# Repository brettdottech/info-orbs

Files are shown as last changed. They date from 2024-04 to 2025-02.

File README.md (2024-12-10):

# Welcome to Info Orbs
Info Orbs is an open source display widget built on top of the ESP32 platform. The device can be used to display a variety of different widgets catered to many different use cases (:

**Version 1.1 of the firmware is here, you can find the new features outlined below. If you're coming from Youtube, the software flashing instructions have changed slightly, *please refer to *[the NEW FLASHING INSTRUCTIONS](references/Firmware%20Install%20Guide.md)* to ensure you get up and running smoothly.***

Quick Links: [Get A Dev Kit Here](https://brett.tech/collections/electronics-projects/products/info-orbs-full-dev-kit) | [Discord](https://link.brett.tech/discord) | [Youtube Assembly/Flashing Video](https://link.brett.tech/orbsYT)
<p>
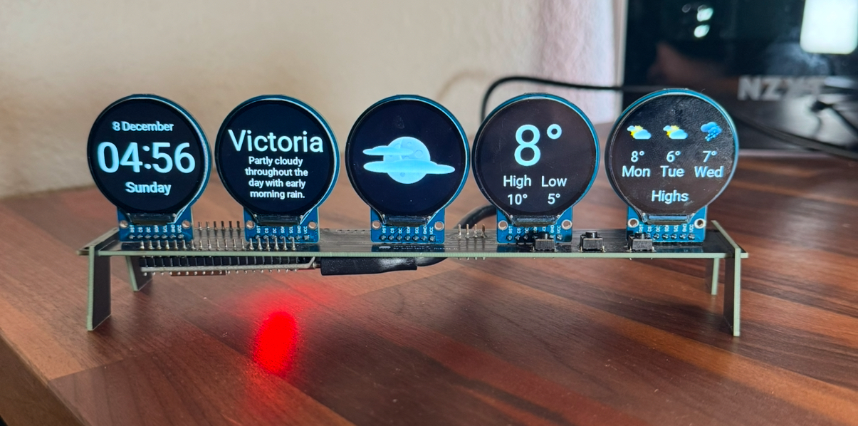
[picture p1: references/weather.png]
Weather Widget
    
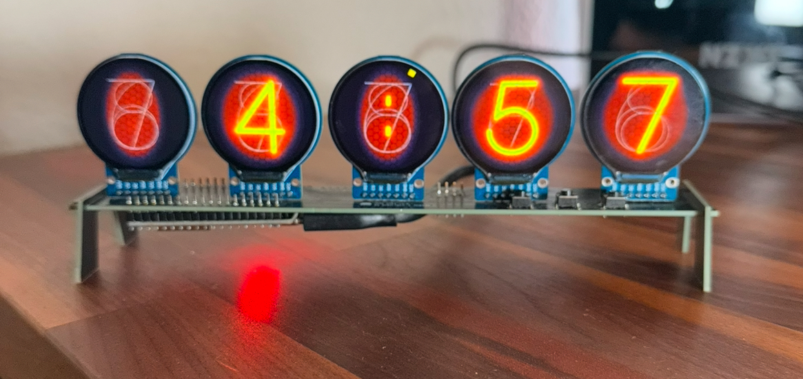
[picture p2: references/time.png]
Clock Widget
    
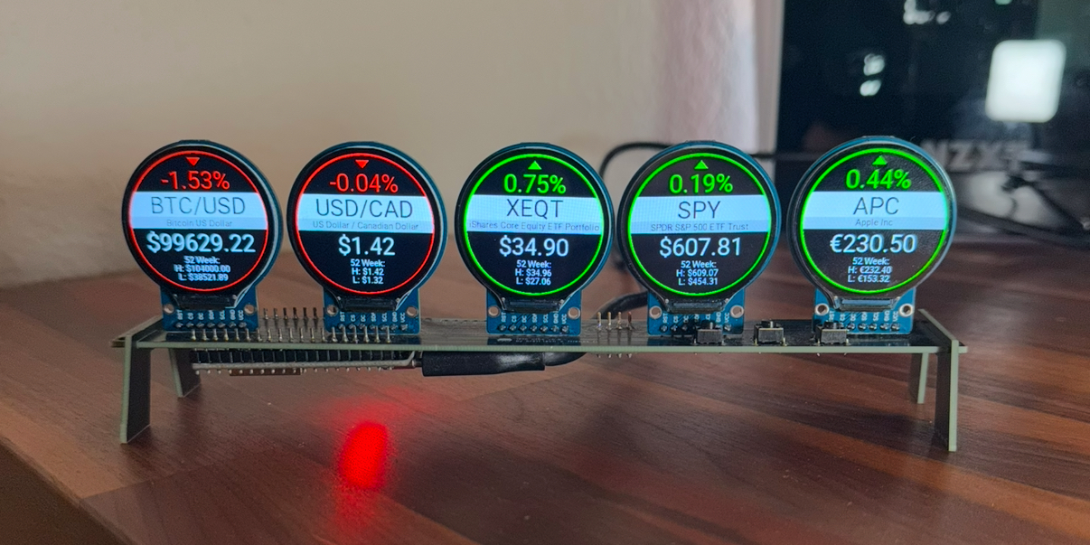
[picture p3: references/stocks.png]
Stock Widget
    
</p>

## First, a few housekeeping items for anyone interested in helping with this project, or building one for themselves

- If you want to contribute and or need a hand with setup, please pop over to the [Discord](https://link.brett.tech/discord). Make sure to select you're there for info orbs when filling out the onboarding questionnaire in order to get placed in the right channels

- I've put together dev kits consisting of all the parts you need to build this project [you can buy them here.](https://brett.tech/collections/electronics-projects/products/info-orbs-full-dev-kit)  They're $60 and will save you a bunch of time and hassle, and are a great way to support the project (:

- I've put together a brief [Youtube Video](https://link.brett.tech/orbsYT) walking through the soldering and flashing for anyone that needs a hand assembling.
## Version 1.1 Release

Version 1.1 is here, in the future releases will be more frequent, but this one is a BIG one bringing some incredible functionality to the project.

**1.1 Changes:**

 1. WifiManager added allowing users to configure/change their Wifi credentials using a friendly in-browser portal.
 2. TTF fonts, giving us much more flexibility in the fonts we use and how they're scaled.
 3. Updated Stock widget with a new look and now supporting international markets, different currencies, crypto and forex.
 4. Nixie Tube clock
 5. Support for users to create their own clocks by simply uploading images for digit
 6. Weather widget "dark mode"
 7. Widget auto-scrolling (switch between widgets automatically ever x seconds)
 8. Screen "Dimming" during certain hours of the day. This is artificial dimming through way of adjusting the colours to be less saturated, but it works very well.
 9. Medium & long press button support to allow for further on device configurations
 10. MQTT widget introduced to display data from and MQTT broker, with a [home assistant blueprint available](https://github.com/dreed47/info-orbs-mqtt-ha).  
 11. Multi Language support for the weather widget

 ..plus LOTS more, this was a big one, thank you to all of the community members who made this update happen. I'm excited we get to finally roll it out and share it with you.
## Getting Up And Running

### 1. Hardware/Wiring
If you use the PCB soldering should be straight forward, however if you want to wire thing up yourself the pinouts are below:

    DSP-----ESP
    SDA -> G17 
    SCLK -> G23 
    DC -> G19 
    RST -> G18
    VCC - >5V/VCC 
    GND -> GND
    Screen1 CS -> G13
    Screen2 CS -> G33
    Screen3 CS -> G32 
    Screen4 CS -> G25
    Screen5 CS -> G21

   Lastly, three pushbuttons between `VCC/5V` and `G14,G26,G27.`
Diagram can be seen below:
Wiring Diagram

### 2. Dev Environment Setup Config
**IDE Setup**
Start by downloading the most recent codebase from the `main` branch. Should you want to explore the latest and greatest features, you can try flashing the `dev` branch by changing the dropdown at the top left, however this version will be poorly documented and less stable.
While built on Arduino, the codebase for this project has been built using the  [Platform IO IDE](https://platformio.org/), which allows you to compile/run Arduino code in VSC as well as quite a few other creature comfort items.
Once you have platform.io installed and configured in VSC, open the `info-orbs.code-workspace` to being the setup process.

**Project Configuration**
Before compiling/flashing, you'll need to navigate into `firmware` >>`config` directory and make a copy of the file `config.h.template` in the same folder and rename that copy to `config.h` **THIS STEP IS CRITICAL AND YOUR CODE WILL NOT COMPILE IF YOU DONT COPY THIS FILE AND CHANGE THE NAME**

Lastly, open up the `config.h` file you just copied/renamed and adjust the parameters in this file to configure the orbs to your personal needs. You can find more details about each configuration option below.

Once you're done this, you can flash the firmware to your orbs by holding the "boot" button on the ESP32 and clicking the "Upload" arrow at the very bottom bar of VSC.

### 3. Widget Options & Configuration
**Basic Setup Fields**
- Wifi is now configured on device using WifiManager by connected to the devices access point upon boot. However if this does not work, you may manually configure your wifi details using the fields in the config file (only do this as a last resort.)  
  ```c
  //#define WIFI_SSID "MyWiFiRouter" // Wifi router SSID name (use only 2.4 GHz   network)    
  //#define WIFI_PASS "WiFiPassword" // Wifi router password  
  ```
- Timezone configuration, you will need to change the below field to your local timezone, or timezone you want displayed on the devices clock(s). Please copy/paste the exact timezone as outline in this list <https://timezonedb.com/time-zones>  
  ```c
  #define TIMEZONE_API_LOCATION "America/Vancouver" // Use timezone from this   list: https://timezonedb.com/time-zones
  ```

- If you want your orbs to automatically cycle widgets, you can change the number from 0 in the below line of code for how many seconds you want to wait between switching, and this will enable that functionality
  ```c
  #define WIDGET_CYCLE_DELAY 0 // Automatically cycle widgets every X seconds, set   to 0 to disable
  ```

- If you want your orbs to "dim" at certain hours of the day you need to uncomment (remove the `//`  at the beginning of the below three lines of code then adjust the starting hour, ending hour, and brightness which you want the dimming to occur.
  ```c
  //#define DIM_START_HOUR 22  // Dim the screens at this time (24h format)
  //#define DIM_END_HOUR 7     // Undim the screens at this time (24h format)
  //#define DIM_BRIGHTNESS 128 // Dim brightness (0-255)
  ```

**Widgets & Widget Settings**
1. **Clock** (Enabled By Default) - this will show the time on the orbs with multiple means of customization. The default settings for the clock will switch between the default and "nixie" style clock upon a short press of the middle button. It will switch between 12/24 hours by a medium press(~0.5 seconds) of the same middle button. The clock has many other configureable elements that can be found in config.h as shown below, feel free to mess around with them to make it your own (:
   ```c
   // CLOCK CONFIGURATION
   # define FORMAT_24_HOUR false            // Toggle 24 hour clock vs 12 hour    clock, change between true/false
   # define SHOW_AM_PM_INDICATOR false      // AM/PM on the clock if using 12   hour
   # define SHOW_SECOND_TICKS true          // Ticking indicator on the centre   clock
   # define CLOCK_COLOR 0xfc80              // Orange for clock
   # define CLOCK_SHADOW_COLOR 0x20a1       // Clock shadow color (Light brown)
   # define CLOCK_SHADOWING true            // Use clock shadow (set to false   to   disable)
   # define USE_CLOCK_NIXIE true            // Set to true to enable Nixie   style   clock
   # define USE_CLOCK_CUSTOM false          // Set to true to enable custom   clock  (see images/ClockWidget/custom/README.md)
   //#define CLOCK_NIXIE_COLOR 0x001f        // Override Nixie color
   # define DEFAULT_CLOCK ClockType::NORMAL // Set the default clock face:       ClockType::NORMAL, ClockType::NIXIE or ClockType::CUSTOM
   //#define CLOCK_FONT DSEG7              // Define clock font (defaults to   DSEG7,    you can also try DSEG14 or FINAL_FRONTIER)
   ```

2. **Weather** (Enabled By Default) - This will show the weather as defined by your weather location. Short pressing the middle button will toggle between the forecast displaying high/low temps, you can also adjust things like your unit preference and whether you want the "theme" to be dark or light (check out both, they're quite different)
   ```c
   #define WEATHER_LOCATION "Victoria, BC" // City/state for the weather, look it    up on https://www.visualcrossing.com/weather-data
   # define WEATHER_SCREEN_MODE Dark        // Can be either Light or Dark
   # define WEATHER_UNITS_METRIC            // Comment this line out (or delete it)    if you want imperial units for the weather
   ```

3. **Stocks** (Enabled By Default) - This will show 5 pre-defined stocks, their prices, names, daily change, and 52 weeks highs/lows. Pressing the middle button will refresh the prices, they will otherwise update automatically every 15 minutes
There are multiple markets/exchanges supported including crypto and forex, the data for this widget is supplied by twelve-data, info on what data you can pull can be found here: <https://twelvedata.com/exchanges?level=grow>.
Simply adjust the 5 stocks in the config file to change the ones you'd like to track, separated by commas.
- To pull a stock from an international market you may add `&country=Germany` (or which ever country you prefer) to identify your local exchange
- If you're displaying forex or crypto, ensure to include `/USD` (or your given currency) as this will be needed to display the price.
`#define STOCK_TICKER_LIST "BTC/USD,USD/CAD,XEQT,SPY,APC&country=Germany" // Choose 5 securities to track. You can track forex, crypto (symbol/USD) or stocks from any exchange (if one ticker is part of multiple exchanges you can add on "&country=Canada" to narrow down to your ticker)
`

4. **parqet.com** (Disabled By Default) - A popular financial portfolio tracker in Germany, this widget will give you a beautiful real-time display of your data. To enable, remove the `//` in front of the config line, and enter your portfolio ID in-between the `""`
`//#define PARQET_PORTFOLIO_ID "" // set the id of your parqet.com portfolio. Make sure the portfolio is set to public!
`

5. **Dynamic Web Data** (Disabled By Default) [advanced users only]- This widget will allow you to make your own custom widget defined by a JSON payload. Further documentation to come.
   ```c
   //#define WEB_DATA_WIDGET_URL "" // Use this to make your own widgets using an    API/Webdata source
   ```

And thats it, goodluck & happy orbin (:

## Contributors
A massive thank you to the community that has helped, this is my first open source project(honestly first project of any sort) so thy help of all you super smart people has just been so so incredible and I couldn't have got this anywhere near where it is now without everyone. Thanks for building this with me. Love ya'll! ♥️

<a href="https://github.com/brett-dot-tech/info-orbs/graphs/contributors">

</a>

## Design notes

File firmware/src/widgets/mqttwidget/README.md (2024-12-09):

# Using MQTT Widget

To enable MQTTWidget in your setup, do the following:

## Step 1

Add the following to your config.h file
```c
#define MQTT_WIDGET_HOST "192.168.3.40"           // MQTT broker host
#define MQTT_WIDGET_PORT 1883                     // MQTT broker port
#define MQTT_SETUP_TOPIC "info-orbs/setup/orbs"   // Setup topic
#define MQTT_WIDGET_USER "user" // Leave empty if authentication is not required
#define MQTT_WIDGET_PASS "pass" // Leave empty if authentication is not required
```

## Step 2

Publish the following to the MQTT topic you defined above.
(Update the below to suit your setup:)

```json
{
  "orbs": [
    {
      "orbid": 0,
      "orbdesc": "House battery",
      "orb-bg": "TFT_SILVER",
      "orb-textcol": "TFT_BLACK",
      "topicsrc": "hamqtt/sensor/solis_battery_soc/state",
      "xpostxt": 115,
      "ypostxt": 100,
      "xposval": 130,
      "yposval": 140,
      "orbsize": 20,
      "orbvalunit": "%"
    },
    {
      "orbid": 1,
      "orbdesc": "Solar yield",
      "orb-bg": "TFT_BLACK",
      "orb-textcol": "TFT_WHITE",
      "topicsrc": "hamqtt/sensor/solis_power_generation_today/state",
      "xpostxt": 110,
      "ypostxt": 100,
      "xposval": 130,
      "yposval": 140,
      "orbsize": 20,
      "orbvalunit": "kWh"
    },
    {
      "orbid": 2,
      "orbdesc": "PV Solar Today",
      "orb-bg": "TFT_BLUE",
      "orb-textcol": "TFT_WHITE",
      "topicsrc": "hamqtt/sensor/solcast_pv_forecast_forecast_today/state",
      "xpostxt": 110,
      "ypostxt": 100,
      "xposval": 130,
      "yposval": 140,
      "orbsize": 20,
      "orbvalunit": "kWh"
    },
    {
      "orbid": 3,
      "orbdesc": "PV Solar Today+",
      "orb-bg": "TFT_BLUE",
      "orb-textcol": "TFT_WHITE",
      "topicsrc": "hamqtt/sensor/solcast_pv_forecast_forecast_tomorrow/state",
      "xpostxt": 110,
      "ypostxt": 100,
      "xposval": 130,
      "yposval": 140,
      "orbsize": 20,
      "orbvalunit": "kWh"
    },
    {
      "orbid": 4,
      "orbdesc": "Garage temp",
      "orb-bg": "TFT_BLUE",
      "orb-textcol": "TFT_WHITE",
      "topicsrc": "zigbee2mqtt/Garage Temp2",
      "xpostxt": 110,
      "ypostxt": 100,
      "xposval": 130,
      "yposval": 140,
      "orbsize": 20,
      "orbvalunit": "°c",
      "jsonfield": "temperature"
    }
  ]
}
```

**Note:** For Orbid 4, there's an additional jsonfield that is used to extract a value from a JSON payload returned from the topic `zigbee2mqtt/Garage Temp2`.

Example 1 payload:
```json
{
    "battery": 100,
    "humidity": 56.7,
    "linkquality": 69,
    "temperature": 17.8
}
```

To extract `temperature`, use: `"jsonfield": "temperature"`

Example 2 payload:
```json
{
    "brightness": 132,
    "linkquality": 140,
    "update": {
        "state": "idle"
    }
}
```

To extract `state`, use: `"jsonfield": "update.state"`

Example 3 payload:
```json
{
    "power_delivered": [
        {
            "value": 0.321,
            "unit": "kW"
        }
    ]
}
```

To extract `value`, use: `"jsonfield": "power_delivered[0].value"`

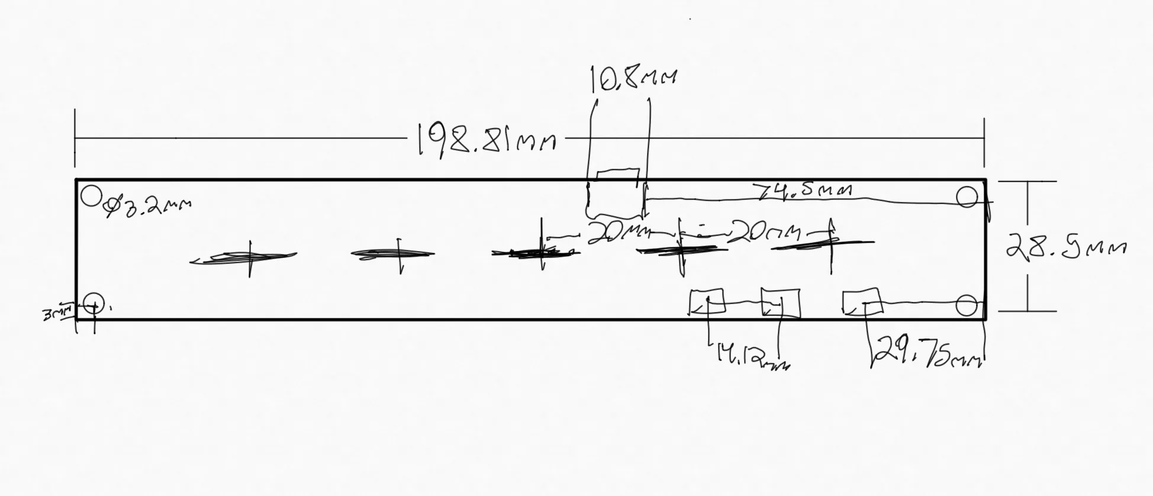
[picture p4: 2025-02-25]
PCBFiles+Schematics/PCB_Dimensions_.webp

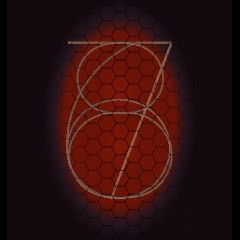
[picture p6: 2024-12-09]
images/ClockWidget/nixie.no-holes/colon_off.jpg

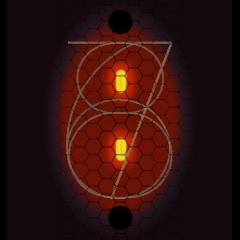
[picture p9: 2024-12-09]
images/ClockWidget/nixie.holes/colon_on.jpg

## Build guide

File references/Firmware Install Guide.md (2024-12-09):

# Info Orbs Firmware Install Guide
Tip: If you're coming from the Youtube video, skip to step 11, as all the earlier steps for installing all the prerequisites are the same. The install process is still very similar, just some config settings and file locations have changed

1\. Download, unzip and install the CP210x drivers needed to connect the device to you computer from <https://www.silabs.com/developer-tools/usb-to-uart-bridge-vcp-drivers?tab=downloads>

Ensure to select the correct operating system for the computer you're using.



2\. Ensure to go through the entire install process, it should be very straight forward



3\. Download, unzip and install the VSC code editor from <https://code.visualstudio.com/download>
Ensure to select the correct operating system for the computer you're using.



4\. Once installed, open VSC



5\. Select the extensions menu on the left hand sidebar.



6\. Search for "PlatformIO", and install it by clicking the install button in the searched list



7\. Fully close out of VSC.



8\. Click the Address and search bar text field



9\. Navigate to <https://github.com/brettdottech/info-orbs> and download the latest firmware for the device by clicking on the green "Code" button, and the selecting "Download ZIP", then unzip that file



10\. Open the file you just downloaded



11\. Open the file called"info-orbs.code-workspace"



12\. Platform IO will need to configure a bunch of things in the background, this can take as long as 10 minutes, wait before this box at the bottom right is gone before you proceed



13\. On the left hand menu, navigate to "config" file directory



14\. Rename the "config.h.template" file to just "config.h" (this is a critical step that will result in your code not being able to otherwise compile.



15\. Open the config.h file by clicking on it, this is where your will configure your settings for the project, please feel free to play around with the many stylistic/preferential settings, however below are the critical ones: \
Change your time zone for the clock(s), you just replace the placeholder "American/Vancouver" with your local timezone identified from this list: [[[https://timezonedb.com/time-zones]]](https://timezonedb.com/time-zones)



16\. change the 24 hour clock format to true for a 24 hour clock, or remain it as false for a 12 hour clock



17\. Configure your location for the weather widget using the format city,statecode



18\. Set your 5 stocks to be displayed on the stock widget, entering all 5 in a single line as stated in the example, separated by commas.\
- To pull a stock from an international market you may add `&country=Germany` (or which ever country you prefer) to identify your local exchange
- If you're displaying forex or crypto, ensure to include `/USD` (or your given currency) as this will be needed to display the price.



19\. Now we're ready to flash the orbs with our firmware, first hold the "boot" button on your esp32



20\. While holding the button, click the arrow symbol at the bottom of your VSC window



21\. The code will take 15 seconds  -  1 minute to compile, keep holding down the boot button until you see "Writing at..." appear in the terminal window, at which point you can release the button



22\. Once flashed, you should see this welcome screen, we now just need to configure our wifi credentials. \
Take note of the wifi network name your orbs are broadcasting, it will be Info-Orbs_xx



23\. Connect to that wifi network using a computer or phone.



24\. You should see this window pop up when you connect to the wifi network (may take a few seconds)



25\. Should you be connected to the network and the window not pop up for some reason, you can navigate to the IP address listed on your orbs in a chrome browser as another means to access this window.



26\. Click "Configure WiFi"



27\. Enter your wifi credentials (a list of networks will also appear above to help aid in this), then click save.



28\. Your orbs are now connected to wifi and you are done!\
\
If you enter your credentials wrong, or if you ever want to change wifi networks, simply hold the far right button on your orbs while powering them on and it will reset the credentials, allowing you to access the wifi portal again (:



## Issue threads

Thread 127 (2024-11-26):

Pick a C++ coding standard and enforce/apply it in PR

lyricnz, 2024-11-26:
At the moment there are a lot of inconsistencies in the codebase: placement of curly-braces, variable naming, whitespace and newlines, indenting, tabs vs spaces etc. Using a more consistent standard will make it easier for contributors (one less degree of freedom to worry about), and potentially expose some kinds of coding errors.

https://isocpp.org/wiki/faq/coding-standards

Ideally, this should be based on one of the built-in clang-format styles. https://clang.llvm.org/docs/ClangFormatStyleOptions.html

lyricnz, 2024-11-26:
Also, add .editorconfig or lint configuration files to the repo so that common editors (eg: vscode) will use this formatting by default.

lyricnz, 2024-11-27:
After discussion in #orbs-software-dev discord channel, the consensus seems to be using clang-format with the following configuration:

```json
{
  BasedOnStyle: LLVM,
  UseTab: Never,
  IndentWidth: 4,
  BreakBeforeBraces: Attach,
  AllowShortIfStatementsOnASingleLine: false,
  AllowShortCaseLabelsOnASingleLine: false,
  IndentCaseLabels: false,
  ColumnLimit: 0,
  AccessModifierOffset: -4,
  NamespaceIndentation: All,
  FixNamespaceComments: false,
  AlignConsecutiveAssignments: false,
  AlignAfterOpenBracket: true,
  AlignTrailingComments: false,
  IndentPPDirectives: BeforeHash,
  SpaceAfterCStyleCast: true,
}
```

I'll implement this, and a matching cpplint config, and CI which enforces it; immediately after a current refactor (moving files around) is completed.

lyricnz, 2024-11-30:
This is https://github.com/brettdottech/info-orbs/pull/131

Closed 2024-12-01.

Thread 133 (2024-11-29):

Resolve deprecation warnings in MQTT widget

lyricnz, 2024-11-29:
After https://github.com/brettdottech/info-orbs/pull/132 is merged

```
Compiling .pio/build/esp32doit-devkit-v1/src/widgets/stockwidget/StockDataModel.cpp.o
firmware/src/widgets/mqttwidget/mqttWidget.cpp: In member function 'void MQTTWidget::callback(char*, byte*, unsigned int)':
firmware/src/widgets/mqttwidget/mqttWidget.cpp:165:21: warning: 'template<unsigned int N> class ArduinoJson::V721PB22::StaticJsonDocument' is deprecated: use JsonDocument instead [-Wdeprecated-declarations]
                     StaticJsonDocument<3072> dataDoc;
                     ^~~~~~~~~~~~~~~~~~
In file included from .pio/libdeps/esp32doit-devkit-v1/ArduinoJson/src/ArduinoJson.hpp:56,
                 from .pio/libdeps/esp32doit-devkit-v1/ArduinoJson/src/ArduinoJson.h:9,
                 from firmware/src/widgets/mqttwidget/mqttWidget.h:7,
                 from firmware/src/widgets/mqttwidget/mqttWidget.cpp:4:
.pio/libdeps/esp32doit-devkit-v1/ArduinoJson/src/ArduinoJson/compatibility.hpp:63:58: note: declared here
 class ARDUINOJSON_DEPRECATED("use JsonDocument instead") StaticJsonDocument
                                                          ^~~~~~~~~~~~~~~~~~
firmware/src/widgets/mqttwidget/mqttWidget.cpp: In member function 'void MQTTWidget::handleSetupMessage(const String&)':
firmware/src/widgets/mqttwidget/mqttWidget.cpp:257:5: warning: 'template<unsigned int N> class ArduinoJson::V721PB22::StaticJsonDocument' is deprecated: use JsonDocument instead [-Wdeprecated-declarations]
     StaticJsonDocument<2048> doc;
     ^~~~~~~~~~~~~~~~~~
In file included from .pio/libdeps/esp32doit-devkit-v1/ArduinoJson/src/ArduinoJson.hpp:56,
                 from .pio/libdeps/esp32doit-devkit-v1/ArduinoJson/src/ArduinoJson.h:9,
                 from firmware/src/widgets/mqttwidget/mqttWidget.h:7,
                 from firmware/src/widgets/mqttwidget/mqttWidget.cpp:4:
.pio/libdeps/esp32doit-devkit-v1/ArduinoJson/src/ArduinoJson/compatibility.hpp:63:58: note: declared here
 class ARDUINOJSON_DEPRECATED("use JsonDocument instead") StaticJsonDocument
                                                          ^~~~~~~~~~~~~~~~~~
Compiling .pio/build/esp32doit-devkit-v1/src/widgets/stockwidget/StockWidget.cpp.o
firmware/src/widgets/mqttwidget/mqttWidget.cpp:287:43: warning: 'ArduinoJson::V721PB22::detail::enable_if_t<ArduinoJson::V721PB22::detail::IsString<TChar*>::value, bool> ArduinoJson::V721PB22::JsonObject::containsKey(TChar*) const [with TChar = const char; ArduinoJson::V721PB22::detail::enable_if_t<ArduinoJson::V721PB22::detail::IsString<TChar*>::value, bool> = bool]' is deprecated: use obj["key"].is<T>() instead [-Wdeprecated-declarations]
         if (orbObj.containsKey("jsonfield")) {
                                           ^
In file included from .pio/libdeps/esp32doit-devkit-v1/ArduinoJson/src/ArduinoJson.hpp:30,
                 from .pio/libdeps/esp32doit-devkit-v1/ArduinoJson/src/ArduinoJson.h:9,
                 from firmware/src/widgets/mqttwidget/mqttWidget.h:7,
                 from firmware/src/widgets/mqttwidget/mqttWidget.cpp:4:
.pio/libdeps/esp32doit-devkit-v1/ArduinoJson/src/ArduinoJson/Object/JsonObject.hpp:178:62: note: declared here
   detail::enable_if_t<detail::IsString<TChar*>::value, bool> containsKey(
                                                              ^~~~~~~~~~~

```

flattermann, 2024-11-29:
Fixed by PR #134

Closed 2024-11-29.

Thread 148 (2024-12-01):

Make network calls async

flattermann, 2024-12-01:
We should try to make the network calls asynchronous.

At the moment, the UI is completely blocked during updates. This is bad for UX, because the buttons don't work and the Orbs are "frozen".

lyricnz, 2024-12-01:
Also, it would be good to be able to switch from the "loading screens" to the first widget before all the widgets had updated their data (faster bootup time)

brett-dot-tech, 2024-12-10:
@dreed47 made some huge progress here, but keeping this issue open as the async fix has resulted in some minor UX bugs #171 , and we have yet to roll it out globally to other widgets (weather). @learn-more suggested some sort of globalized function to handle such async calls which I think sounds like a good idea

flattermann, 2024-12-12:
We just have to make sure that only one HTTP request is running at a time, because a HTTPClient with ArduinoJson parsing will easily use 70-100kB RAM and at the moment, the Orbs only have ~130kB free RAM when idle.
So if we switch all widgets to async/tasks, this will become an issue at boot.

dreed47, 2024-12-12:
Maybe we could use a Task semaphore to only allow one HTTP request at a time.  It would require us moving all the HTTP requests to use Tasks.  Or possible create a HTTP helper class or method the we use instead that wraps the Task and semaphore stuff and maybe JSON filtering too?

lyricnz, 2025-01-11:
This is essentially #222 now, right?

dreed47, 2025-01-11:
yes I think so

flattermann, 2025-03-02:
Implemented for WeatherWidget, StockWidget and ParqetWidget now.

Closed 2025-03-02.

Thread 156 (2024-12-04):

Middle Second 2 dot flash not working

Dragonfire3296, 2024-12-04:
Hi All,

In my board the middle 2 dot flash for the seconds tick seems to have issues after some time, I will add a video to show.

https://github.com/user-attachments/assets/4fa3b3ed-ec49-4102-ad06-12611f606771

Dragonfire3296, 2025-01-14:
I have the latest DEV build running and just noticed that this has started again after about 5 days. Any troubleshooting I can help with?

HugoBalder, 2025-02-05:
Tried it again, startet the orb, everything was loaded fine and then i disabled my hotspot on my iphone (have to use this, as the wifi in the office has a firewall).

After it had no internet anymore, the colon in the middle is refreshed sporadically and the second dot jumps only every 2 seconds.

So finally everyone can reproduce it - no wifi, lagging middle screen.

Dragonfire3296, 2025-02-05:
I know on mine it is still connected to the network though...is there a wAy to double check?Get Outlook for AndroidFrom: HugoBalder ***@***.***>Sent: Wednesday, February 5, 2025 7:49:48 a.m.To: brettdottech/info-orbs ***@***.***>Cc: Dragonfire3296 ***@***.***>; Author ***@***.***>Subject: Re: [brettdottech/info-orbs] Middle Second 2 dot flash not working (Issue #156)
Tried it again, startet the orb, everything was loaded fine and then i disabled my hotspot on my iphone (have to use this, as the wifi in the office has a firewall).
After it had no internet anymore, the colon in the middle is refreshed sporadically and the second dot jumps only every 2 seconds.
So finally everyone can reproduce it - no wifi, lagging middle screen.

—Reply to this email directly, view it on GitHub, or unsubscribe.You are receiving this because you authored the thread.Message ID: ***@***.***>

HugoBalder, 2025-02-05:
I would connect the esp32 to my pc and in visual code run the serial monitor and look on the output. Maybe in your environment you have at some time more than one device with the same IP address.
Look if you see the lines i posted with beginpacket and endpacket. This stuff is blocking the orb. Don‘t know who implemented it, maybe this person should try, if this behaviour can be changed. Now as we know how to get to this error, it is simple to reproduce it.

HugoBalder, 2025-02-06:
Now i have found a second reason, why this occurs.
It also happens, when the ntp-server pool.ntp.org cannot be reached. In the office our wifi with the firewall can load the stocks and the weather, but the ntp-port is blocked. Therefore also the second tick is updated only every 2 seconds and the colon is not redrawn.

Dragonfire3296, 2025-02-06:
I am checking now, I have the monitor running.

From: "Mark Jansen" ***@***.***>
To: "brettdottech/info-orbs" ***@***.***>
Cc: "Dragonfire3296" ***@***.***>, "Author" ***@***.***>
Sent: Thursday, February 6, 2025 2:25:06 AM
Subject: Re: [brettdottech/info-orbs] Middle Second 2 dot flash not working (Issue #156)

A blocking network call sounds like a very reasonable explanation why this sometimes happens, and only for some people.

—
Reply to this email directly, [ https://github.com/brettdottech/info-orbs/issues/156#issuecomment-2639258729 | view it on GitHub ] , or [ https://github.com/notifications/unsubscribe-auth/BIZGRANIKCIQHKQPSITKF3L2OMS7FAVCNFSM6AAAAABTBHEFG2VHI2DSMVQWIX3LMV43OSLTON2WKQ3PNVWWK3TUHMZDMMZZGI2TQNZSHE | unsubscribe ] .
You are receiving this because you authored the thread. Message ID: ***@***.***>

Dragonfire3296, 2025-02-10:
Finally got it to go, but different error, same vein:
Drawing of Clock took 455 ms
[97613397][E][WiFiUdp.cpp:172] beginPacket(): could not get host from dns: 11
[190450963][E][WiFiUdp.cpp:172] beginPacket(): could not get host from dns: 11
[225515407][E][WiFiUdp.cpp:172] beginPacket(): could not get host from dns: 11
[246186984][E][WiFiUdp.cpp:172] beginPacket(): could not get host from dns: 11
[254554744][E][WiFiUdp.cpp:172] beginPacket(): could not get host from dns: 11
[327625046][E][WiFiUdp.cpp:172] beginPacket(): could not get host from dns: 11

Dragonfire3296, 2025-02-10:
I wonder if we just right in a clause to restart if it detects errors?

HugoBalder, 2025-02-10:
Maybe you have a DNS Server set in your router like 8.8.8.8 instead of the dns server from your provider. In the info orb wifi settings we cannot set any dns server. Only a few people posted this error in the github repository of the wifimanager.

ScottWell1, 2025-02-24:
I occasionally see this same issue (colon stops flashing).

In my environment, all NTP calls are intercepted and handled by the router's internal ntpd daemon.  Loss of WAN entirely, or loss of DNS resolution to pool.ntp.org, or lack from response from pool.ntp.org, would have no effect here.  As long as the router is up, ntp requests are all handled locally.

Could a blocking network call (with failed DNS or no response) from another widget, like weather or stocks, be the cause?  I didn't think those requested any data until cycling to that widget, but I don't know the code that well.

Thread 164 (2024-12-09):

WebPortal improvements

flattermann, 2024-12-09:
From Andrea at discord:

Info_Orbs WiFiManager

Ideas:
Button for the main-page on each page

on the buttons page
after reboot
e.g.
Module will reset in a few seconds.
[ Back to main-page]
...

.../info?:
Available pages
 /buttons

Available commands
e.g.
normal GET request, e.g. in your browser:
http://<Info-Orbs-IP>/button?name=right&state=short
name can be left/middle/right and state can be short/medium/long

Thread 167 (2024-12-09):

Add input filters on all JSON payload

brett-dot-tech, 2024-12-09:
As we enable multiple widgets on device we may soon run into memory issues. Filtering the larger JSON payload like the weather API could help with this significantly https://arduinojson.org/news/2020/03/22/version-6-15-0/

flattermann, 2025-03-02:
Do we still need to implement filters anywhere?

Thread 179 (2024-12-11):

Add NTP server to the list of things configurable from the web portal.

gadget-fan, 2024-12-11:
I think it would be useful to be able to alter the NTP server name from the web portal.  Maybe have some way to automatically populate with the default or enter your own.

flattermann, 2024-12-13:
Implemented in current WebPortal branch.

Closed 2024-12-13.

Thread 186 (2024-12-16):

clockwidget update function strange code in first line

HugoBalder, 2024-12-16:
The if line should be removed, because it is doing nothing useful. The variable m_secondTimerPrev is set only ONCE in the clockwidget.h to 0.
After that it is never assigned a new value.

So this condition is always false, as millis - 0 is always greater than 2000.

void ClockWidget::update(bool force) {
    if (millis() - m_secondTimerPrev < m_secondTimer && !force) {
        return;
    }

flattermann, 2025-03-02:
Fixed by #250

Closed 2025-03-02.

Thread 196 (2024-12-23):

Please delete issue, it was resolved with a restart

ptparker, 2024-12-23:
Team, getting the following error when trying to do a vanilla install: I have not altered anything that would affect these files, just timezone, wifi, "#define FORMAT_24_HOUR false", weather location, and a couple stock tickers. Any thoughts?

```
Processing esp32doit-devkit-v1 (platform: espressif32; board: esp32doit-devkit-v1; framework: arduino)
---------------------------------------------------------------------------------------------------------------------------------------------------------------------------------------------------------------------------------------------
Verbose mode can be enabled via `-v, --verbose` option
CONFIGURATION: https://docs.platformio.org/page/boards/espressif32/esp32doit-devkit-v1.html
PLATFORM: Espressif 32 (6.9.0) > DOIT ESP32 DEVKIT V1
HARDWARE: ESP32 240MHz, 320KB RAM, 4MB Flash
DEBUG: Current (cmsis-dap) External (cmsis-dap, esp-bridge, esp-prog, iot-bus-jtag, jlink, minimodule, olimex-arm-usb-ocd, olimex-arm-usb-ocd-h, olimex-arm-usb-tiny-h, olimex-jtag-tiny, tumpa)
PACKAGES:
 - framework-arduinoespressif32 @ 3.20017.241212+sha.dcc1105b
 - tool-esptoolpy @ 1.40501.0 (4.5.1)
 - toolchain-xtensa-esp32 @ 8.4.0+2021r2-patch5
LDF: Library Dependency Finder -> https://bit.ly/configure-pio-ldf
LDF Modes: Finder ~ chain, Compatibility ~ soft
Found 42 compatible libraries
Scanning dependencies...
Dependency Graph
|-- SPI @ 2.0.0
|-- FS @ 2.0.0
|-- SPIFFS @ 2.0.0
|-- LittleFS @ 2.0.0
|-- SD @ 2.0.0
|-- NTPClient @ 3.2.1
|-- ArduinoJson @ 7.2.1
|-- StreamUtils @ 1.9.0
|-- TFT_eSPI @ 2.5.43
|-- TJpg_Decoder @ 1.1.0
|-- PubSubClient @ 2.8.0
|-- Time @ 1.6.1
|-- WiFiManager @ 2.0.17
|-- HTTPClient @ 2.0.0
|-- WiFi @ 2.0.0
|-- OpenFontRender
Building in release mode
Compiling .pio\build\esp32doit-devkit-v1\src\core\button\Button.cpp.o
firmware/src/core/button/Button.cpp: In member function 'void Button::begin()':
firmware/src/core/button/Button.cpp:13:20: error: 'BUTTON_MODE' was not declared in this scope
     pinMode(m_pin, BUTTON_MODE);
                    ^~~~~~~~~~~
compilation terminated due to -Wfatal-errors.
Compiling .pio\build\esp32doit-devkit-v1\src\core\globaltime\GlobalTime.cpp.o
*** [.pio\build\esp32doit-devkit-v1\src\core\button\Button.cpp.o] Error 1
In file included from firmware/src/core/globaltime/GlobalTime.cpp:1:
firmware/src/core/globaltime/GlobalTime.h:82:25: error: 'FORMAT_24_HOUR' was not declared in this scope
     bool m_format24hour{FORMAT_24_HOUR};
                         ^~~~~~~~~~~~~~
compilation terminated due to -Wfatal-errors.
*** [.pio\build\esp32doit-devkit-v1\src\core\globaltime\GlobalTime.cpp.o] Error 1
======================================================================================================== [FAILED] Took 10.30 seconds ========================================================================================================

 *  The terminal process "C:\Users\ptparker\.platformio\penv\Scripts\platformio.exe 'run'" terminated with exit code: 1.
 *  Terminal will be reused by tasks, press any key to close it.

```

Closed 2024-12-23.

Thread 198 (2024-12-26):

Questions

Mikede78, 2024-12-26:
1. Can I edit the config to make changes after its setup? If so how?
2. Is there an option to turn off the red light on the ESP32 chip?
3. Are there any clock images besides the default one?

HugoBalder, 2024-12-27:
1. the config cannot be edited after it is flashed to the esp, but on the Webpage you can change tons of settings, when the device is on.
2. the red LED is directly connected to power and cannot be turned on/off by software. You have to desolder it.
3. Join the discord channel, there are many links and discussions about custom clock faces.

flattermann, 2024-12-31:
1. If you flash the newest dev firmware, you can open the WebPortal once your Orbs are connected to your Wifi: http://ip-of-your-orbs
2. As @HugoBalder said, that's not controllable by software
3. Joining the discord is always a good idea. :-) Here are some links to custom clocks:

https://github.com/AndreaFontolan/Info-Orbs-Clockfaces
https://info-orbs-clock-style-showcase.pages.dev/

In the newest dev version, you can go to the "File Browser", open a CustomClock directory and directly paste one of the URLs from the repos above to let the Orbs download the clock images, e.g.

https://github.com/AndreaFontolan/Info-Orbs-Clockfaces/tree/main/Binary%20clock%201
or
https://info-orbs-clock-style-showcase.pages.dev/images/10/

Closed 2024-12-31.

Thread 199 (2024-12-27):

"Error; please specify "upload_port"

azey23, 2024-12-27:
Error: Please specify `upload_port` for environment or use global `--upload-port` option.
For some development platforms it can be a USB flash drive (i.e. /media/<user>/<device name>)
*** [upload] Explicit exit, status 1

Anyone seen this error before? Cannot find where to specify

azey23, 2024-12-27:
Thanks Hugo - I still cannot seem to locate this in platformo.ini

Is there a screenshot anywhere I can use? Thanks

HugoBalder, 2024-12-27:
You have ro add a new line with upload_port = COM<number> in this section of platformio.ini
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

azey23, 2024-12-27:
Next problem; I don't have usb's numbered in device manager. (COM3, ect)

I have "Universal Series bus controllers" but they name driver types.

Is there an alternative solution?

//acer Nitro 5

HugoBalder, 2024-12-27:
Watch the Youtube Video from Brett and start at Minute 13, there is everything described how to flash and install everything.

azey23, 2024-12-27:
Yes, didn't help unfortunately. However, I connected USB-C to USB-C and it worked! In case anyone else struggling with this

Closed 2024-12-27.

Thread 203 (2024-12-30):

Implement ArduinioLog for better log message control

dreed47, 2024-12-30:
t's pretty lightweight and it would give us the ability to better control what gets printed to the Serial Monitor.  It supports these log types.

```
// Log levels: 0 (SILENT), 1 (FATAL), 2 (ERROR), 3 (WARNING),
// 4 (NOTICE), 5 (TRACE), 6 (VERBOSE)
#define LOG_LEVEL LOG_LEVEL_VERBOSE
```

So instead of
`Serial.println("Starting up...");`
  It would be something like
`Log.noticeln("Starting up...");`

For reference here's the [github page for ArduinoLog](https://github.com/thijse/Arduino-Log).

Closed 2025-01-09.

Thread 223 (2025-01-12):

Inaccurate timing for first stock rendering

lyricnz, 2025-01-12:
No, it didn't take 93 seconds to render the BTC/USD ticker - it was on the previous screen

```
I: Left button short pressed -> switch to prev Widget
displayStock - BTC/USD ~ 93879.93
displayStock - USD/CAD ~ 1.44
displayStock - XEQT ~ 33.56
displayStock - SPY ~ 580.49
displayStock - APC&country=Germany ~ 228.55
Drawing of Stock took 1221 ms
```

lyricnz, 2025-01-12:
Cycling around all the pages of widgets, and back to the ticker, displays _precisely_ the same values. Suspicious?

```
I: Left button short pressed -> switch to prev Widget
displayStock - BTC/USD ~ 93879.93
displayStock - USD/CAD ~ 1.44
displayStock - XEQT ~ 33.56
displayStock - SPY ~ 580.49
displayStock - APC&country=Germany ~ 228.55
Drawing of Stock took 1221 ms
I: Left button short pressed -> switch to prev Widget
Drawing of Weather took 755 ms
I: Left button short pressed -> switch to prev Widget
Drawing of Clock took 459 ms
I: Left button short pressed -> switch to prev Widget
displayStock - BTC/USD ~ 93879.93
displayStock - USD/CAD ~ 1.44
displayStock - XEQT ~ 33.56
displayStock - SPY ~ 580.49
displayStock - APC&country=Germany ~ 228.55
Drawing of Stock took 1221 ms
```

flattermann, 2025-01-12:
The numbers are not timings, they are the stock prices, e.g. 93879.93 $ per BTC. :-)

lyricnz, 2025-01-13:
Hahahah, ok!

Closed 2025-01-13.

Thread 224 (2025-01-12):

Output of "garbage" on serial port

lyricnz, 2025-01-12:
The lines of silly character may be mangled by my terminal, but something is being output there:

```
I: ✅ Released semaphore
I: 🔵 Starting HTTP request for: https://api.twelvedata.com/quote?apikey=e03fc53524454ab8b65d91b23c669cc5&symbol=APC&country=Germany
I: ✅ Released semaphore
����������������������������������������������������������������1
I: Left button short pressed -> switch to prev Widget
displayStock - BTC/USD ~ 93879.93
displayStock - USD/CAD ~ 1.44
displayStock - XEQT ~ 33.56
displayStock - SPY ~ 580.49
displayStock - APC&country=Germany ~ 228.55
Drawing of Stock took 1221 ms
����������������������������������������������������������������
```

dreed47, 2025-02-28:
I don't see these on my terminal.  Is anyone else seeing them?  I'm on MacOS

dreed47, 2025-03-01:
I have a theory that these garbage characters are a result of electrical interference.  Let me explain why I say that.  First, I hardly ever see them and I understand many people see them all the time.  This leads me to believe its a local environmental issue.  Second they seem to appear at random points in the app execution.  Third they seem to print without a line feed.  I did a search through the code to find places where we do a Serial.print (not Serial.println) and there are only a few and none of them seem like likely candidates.   Electrical interference can come from bad usb cables, nearby devices, motors, or power supplies. Long cables act as antennas, picking up noise and degrading the signal.  Adjacent wires interfering with each other can corrupt the data.

flattermann, 2025-03-02:
Startup garbage character should be taken care by #246.

But we cannot really do something about electrical interference. :-)

Feel free to reopen if necessary.

lyricnz, 2025-03-04:
FYI: che and I spent quite a bit of time yesterday digging into this - observing the patterns, cutting out code and features (all the way to turning off wifi, all the widgets, and even emptying the main loop()), and still having the same issue.  Finally, we connected the device directly to PC, and not via USB hub, and problem went away.

Closed 2025-03-02.

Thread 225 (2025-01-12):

Frequent errors about timezone updates, including errors

lyricnz, 2025-01-12:
I happen to be on the stock ticker screen, with default config.h

```
Next timezone update: 1741514613
Timezone Offset from API: -28800
Next timezone update: 1741514536
Timezone Offset from API: -28800
Next timezone update: 1741514642
Timezone Offset from API: -28800
Next timezone update: 1741514596
Timezone Offset from API: -28800
Next timezone update: 1741514554
Timezone Offset from API: -28800
Next timezone update: 1741514560
Timezone Offset from API: -28800
Next timezone update: 1741514578
Deserialization error on timezone offset API response
Deserialization error on timezone offset API response
Deserialization error on timezone offset API response
Deserialization error on timezone offset API response
Deserialization error on timezone offset API response
Deserialization error on timezone offset API response
Deserialization error on timezone offset API response
Deserialization error on timezone offset API response
Deserialization error on timezone offset API response
Timezone Offset from API: -28800
Next timezone update: 1741514607
Timezone Offset from API: -28800
Next timezone update: 1741514537
Timezone Offset from API: -28800
Next timezone update: 1741514637
Timezone Offset from API: -28800
Next timezone update: 1741514695
Timezone Offset from API: -28800
Next timezone update: 1741514584
Timezone Offset from API: -28800
Next timezone update: 1741514505
Timezone Offset from API: -28800
Next timezone update: 1741514444
Deserialization error on timezone offset API response
Deserialization error on timezone offset API response
Deserialization error on timezone offset API response
Deserialization error on timezone offset API response
Deserialization error on timezone offset API response
Deserialization error on timezone offset API response
Deserialization error on timezone offset API response
Deserialization error on timezone offset API response
Deserialization error on timezone offset API response
Timezone Offset from API: -28800
```

flattermann, 2025-01-12:
That's strange. It should only update the TZ Offset twice per year (after DST change).

```
if (m_timeZoneOffset == -1 || (m_nextTimeZoneUpdate > 0 && m_unixEpoch > m_nextTimeZoneUpdate)) {
  getTimeZoneOffsetFromAPI();
}
```

Clearly, the `m_timeZoneOffset` was fetched/set correctly (to -28800) and the `m_nextTimeZoneUpdate` is also correct (1741514xxx).

lyricnz, 2025-01-13:
```
Next timezone update: 1741514613
Timezone Offset from API: -28800
Next timezone update: 1741514536
Timezone Offset from API: -28800
Next timezone update: 1741514642
Timezone Offset from API: -28800
Next timezone update: 1741514596
Timezone Offset from API: -28800
```

FWIW:
- 1741514613 = Sun Mar 09 2025 10:03:33 GMT+0000
- 1741514536 = Sun Mar 09 2025 10:02:16 GMT+0000
- 1741514642 = Sun Mar 09 2025 10:04:02 GMT+0000
- 1741514596 = Sun Mar 09 2025 10:03:16 GMT+0000

So the next-update is jumping around a bit, and is still 2 months in the future.  What's causing it to get reset so often, or queried so often?

lyricnz, 2025-01-13:
I added some debug:

```cpp
void GlobalTime::updateTime(bool force) {
    if (force || millis() - m_updateTimer > m_oneSecond) {
        Serial.println("GlobalTime::updateTime - inside1");
        if (m_timeZoneOffset == -1 || (m_nextTimeZoneUpdate > 0 && m_unixEpoch > m_nextTimeZoneUpdate)) {
            Serial.printf("GlobalTime::updateTime - inside2: m_timeZoneOffset: %d; m_nextTimeZoneUpdate=%d; m_unixEpoch=%d\n", m_timeZoneOffset, m_nextTimeZoneUpdate, m_unixEpoch );
            getTimeZoneOffsetFromAPI();
        }
```

And it went from just doing inside1, to doing the actual update (for no obvious reason):

```
GlobalTime::updateTime - inside1

GlobalTime::updateTime - inside1

GlobalTime::updateTime - inside1

GlobalTime::updateTime - inside1

GlobalTime::updateTime - inside2: m_timeZoneOffset: -28800; m_nextTimeZoneUpdate=1741514533; m_unixEpoch=2085949696
Fetching Timezone Offset from API:
Timezone Offset from API: -28800
Next timezone update: 1741514420
GlobalTime::updateTime - inside1

GlobalTime::updateTime - inside2: m_timeZoneOffset: -28800; m_nextTimeZoneUpdate=1741514420; m_unixEpoch=2085949697
Fetching Timezone Offset from API:
Timezone Offset from API: -28800
Next timezone update: 1741514573
GlobalTime::updateTime - inside1

GlobalTime::updateTime - inside2: m_timeZoneOffset: -28800; m_nextTimeZoneUpdate=1741514573; m_unixEpoch=2085949698
Fetching Timezone Offset from API:
Timezone Offset from API: -28800
Next timezone update: 1741514668
GlobalTime::updateTime - inside1
```

That m_unixEpoch looks wrong:
```
1741514407 Sun Mar 09 2025 10:00:07 GMT+0000
1741514651 Sun Mar 09 2025 10:04:11 GMT+0000
2085949740 Wed Feb 06 2036 22:29:00 GMT+0000
```

lyricnz, 2025-01-13:
Change the debug code to:
```cpp
        Serial.printf("GlobalTime::updateTime - inside1: m_timeZoneOffset: %d; m_nextTimeZoneUpdate=%d; m_unixEpoch=%d\n", m_timeZoneOffset, m_nextTimeZoneUpdate, m_unixEpoch );
        if (m_timeZoneOffset == -1 || (m_nextTimeZoneUpdate > 0 && m_unixEpoch > m_nextTimeZoneUpdate)) {
            Serial.println("GlobalTime::updateTime - inside2");
            getTimeZoneOffsetFromAPI();
        }
```

And it starts out ok:
```
GlobalTime::updateTime - inside1: m_timeZoneOffset: -28800; m_nextTimeZoneUpdate=1741514587; m_unixEpoch=1736721898
GlobalTime::updateTime - inside1: m_timeZoneOffset: -28800; m_nextTimeZoneUpdate=1741514587; m_unixEpoch=1736721900
GlobalTime::updateTime - inside1: m_timeZoneOffset: -28800; m_nextTimeZoneUpdate=1741514587; m_unixEpoch=1736721901
GlobalTime::updateTime - inside1: m_timeZoneOffset: -28800; m_nextTimeZoneUpdate=1741514587; m_unixEpoch=1736721902
GlobalTime::updateTime - inside1: m_timeZoneOffset: -28800; m_nextTimeZoneUpdate=1741514587; m_unixEpoch=1736721903
```

Waiting for it to go bad now....

lyricnz, 2025-01-13:
Still haven't hit it yet. "Something" is definitely corrupting m_unixEpoch

lyricnz, 2025-01-13:
I just rebooted the orbi, which triggered the same issue (probably a problem calling web API)

```
WifiManager connected.[  5167][E][Preferences.cpp:483] getString(): nvs_get_str len fail: timezoneLoc NOT_FOUND
[  5185][E][Preferences.cpp:483] getString(): nvs_get_str len fail: ntpServer NOT_FOUND
GlobalTime initialized, tzLoc=America/Vancouver, clockFormat=1, ntpServer=pool.ntp.org
[  5198][E][Preferences.cpp:483] getString(): nvs_get_str len fail: weatherLocation NOT_FOUND
WeatherWidget initialized, loc=Victoria, BC, mode=1
[  5211][E][Preferences.cpp:483] getString(): nvs_get_str len fail: stockList NOT_FOUND
Constructing ParqetWidget, portfolioId=
[  5225][E][Preferences.cpp:483] getString(): nvs_get_str len fail: pqportfoId NOT_FOUND
New config section: General
New config section: TFT Settings
New config section: ClockWidget
New config section: WeatherWidget
New config section: StockWidget
New config section: ParqetWidget
IP address: 192.168.101.71
*wm:Starting Web Portal

Connected to WiFi
updating widget Clock
updating widget Weather
updating widget Stock
GlobalTime::updateTime - inside1: m_timeZoneOffset: -1; m_nextTimeZoneUpdate=0; m_unixEpoch=0
GlobalTime::updateTime - inside2
Fetching Timezone Offset from API:
Timezone Offset from API: -28800
Next timezone update: 1741514594
I: 🔵 Starting HTTP request for: https://weather.visualcrossing.com/VisualCrossingWebServices/rest/services/timeline/Victoria, BC/next3days?key=REMOVED&unitGroup=metric&include=days,current&iconSet=icons1&lang=en
GlobalTime::updateTime - inside1: m_timeZoneOffset: -28800; m_nextTimeZoneUpdate=1741514594; m_unixEpoch=2085949696
GlobalTime::updateTime - inside2
Fetching Timezone Offset from API:
Timezone Offset from API: -28800
Next timezone update: 1741514637
GlobalTime::updateTime - inside1: m_timeZoneOffset: -28800; m_nextTimeZoneUpdate=1741514637; m_unixEpoch=2085949697
```
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
lyricnz, 2025-01-13:
Feels like a bug in error handling in NTPClient. Maybe https://github.com/arduino-libraries/NTPClient/issues/105#issuecomment-656154072

lyricnz, 2025-01-13:
NTP sync returns random day and time for the year 2036
https://github.com/gmag11/NtpClient/issues/70

> Research shows that the time/date 07:28:16 07/02/2036 is the NTP roll-over date. The time stamp in NTP is given in seconds, starting from 1.1.1900 (UNIX starts 1.1.1970).

Which is what we're seeing.

lyricnz, 2025-01-13:
> I think I am starting to understand. There is a method called getTime. This method requests a NTP message from an NTP server and returns the new time. But if there is a timeout, it raises a noResponse ntpEvent and then it returns 0; This 0 then gets interpreted as 02/07/2036.

lyricnz, 2025-01-13:
Yeah it just happened again:

```
GlobalTime::updateTime - inside1: m_timeZoneOffset: -28800; m_nextTimeZoneUpdate=1741514687; m_unixEpoch=1736775418
GlobalTime::updateTime - inside1: m_timeZoneOffset: -28800; m_nextTimeZoneUpdate=1741514687; m_unixEpoch=1736775419
GlobalTime::updateTime - inside1: m_timeZoneOffset: -28800; m_nextTimeZoneUpdate=1741514687; m_unixEpoch=2085949696
GlobalTime::updateTime - inside2
Fetching Timezone Offset from API:
Timezone Offset from API: -28800
Next timezone update: 1741514508
GlobalTime::updateTime - inside1: m_timeZoneOffset: -28800; m_nextTimeZoneUpdate=1741514508; m_unixEpoch=2085949697
GlobalTime::updateTime - inside2
Fetching Timezone Offset from API:
Timezone Offset from API: -28800
Next timezone update: 1741514587
```

lyricnz, 2025-01-13:
It looks like we're hitting the NTP server every minute - that's way too often.

```cpp
        bool wasUpdated = m_timeClient->update();
        m_unixEpoch = m_timeClient->getEpochTime();
        if (wasUpdated) {
            Serial.printf("GlobalTime::updateTime - inside3 - got result %d\n", m_unixEpoch);
        }
```

emits

```
GlobalTime::updateTime - inside3 - got result 1736779208 # Mon Jan 13 2025 14:40:08 GMT+0000
GlobalTime::updateTime - inside3 - got result 1736779268 # Mon Jan 13 2025 14:41:08 GMT+0000
GlobalTime::updateTime - inside3 - got result 1736779329 # Mon Jan 13 2025 14:42:09 GMT+0000
```

lyricnz, 2025-01-13:
Showing error happening from subsystem:

```cpp
    if (force || millis() - m_updateTimer > m_oneSecond) {
        Serial.printf("GlobalTime::updateTime - inside1: m_timeZoneOffset: %d; m_nextTimeZoneUpdate=%d; m_unixEpoch=%d\n", m_timeZoneOffset, m_nextTimeZoneUpdate, m_unixEpoch );
        if (m_timeZoneOffset == -1 || (m_nextTimeZoneUpdate > 0 && m_unixEpoch > m_nextTimeZoneUpdate)) {
            Serial.println("GlobalTime::updateTime - inside2");
            getTimeZoneOffsetFromAPI();
        }
        bool wasUpdated = m_timeClient->update();
        m_unixEpoch = m_timeClient->getEpochTime();
        if (wasUpdated) {
            Serial.printf("GlobalTime::updateTime - inside3 - got result %d\n", m_unixEpoch);
        }
```

emitting

```
lobalTime::updateTime - inside1: m_timeZoneOffset: -28800; m_nextTimeZoneUpdate=1741514694; m_unixEpoch=1736782302
GlobalTime::updateTime - inside1: m_timeZoneOffset: -28800; m_nextTimeZoneUpdate=1741514694; m_unixEpoch=1736782304
GlobalTime::updateTime - inside1: m_timeZoneOffset: -28800; m_nextTimeZoneUpdate=1741514694; m_unixEpoch=1736782306
GlobalTime::updateTime - inside1: m_timeZoneOffset: -28800; m_nextTimeZoneUpdate=1741514694; m_unixEpoch=1736782308
GlobalTime::updateTime - inside3 - got result 2085949696
GlobalTime::updateTime - inside1: m_timeZoneOffset: -28800; m_nextTimeZoneUpdate=1741514694; m_unixEpoch=2085949696
GlobalTime::updateTime - inside2
Timezone Offset from API: -28800
Next timezone update: 1741514399
```

The 208... is "Wed Feb 06 2036 22:28:16 GMT+0000"

We could probably just do a check for date >2030 and ignore it (or retry).

flattermann, 2025-01-14:
This looks like a simple fix, but we would need to use our own patched NTPClient:

https://github.com/arduino-libraries/NTPClient/pull/211/files

flattermann, 2025-03-02:
Fixed by #245

Closed 2025-03-02.

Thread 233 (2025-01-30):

PCB Dimensions and layout

johnwargo, 2025-01-30:
Can you share the pcb measurements file?  I want to 3d print a mounting bracket for the board

learn-more, 2025-01-31:
The complete pcb is shared, that should contain the info you need?
[[info-orbs/tree/main/PCBFiles%2BSchematics/Main%20PCB](url)](https://github.com/brettdottech/info-orbs/tree/main/PCBFiles%2BSchematics/Main%20PCB)

johnwargo, 2025-01-31:
No, it does not, that's why I asked.  I'm not a PCB designer, so I can't pull the information I need out of the files.  Many PCB file sets include an image file that lays out the dimensions, that is what I'm asking for. Like this

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

HugoBalder, 2025-01-31:
The pcb is 194x28mm, just measured it 😀

johnwargo, 2025-01-31:
Yes, I have the dimensions of the board, what I want is just like I showed in the sample image I provided - all of the measurements for the board and holes so I can build an enclosure for it. That means hole dimensions and placement as well.

I assumed that could just be exported from the project, I just don't know anything about board design tools to do that.

HugoBalder, 2025-02-01:
Then buy simply a kit and you have everything 🤦

johnwargo, 2025-02-01:
@HugoBalder that is not helpful.  I have the board already.

Is it that bad that I’m asking for the exact measurements? If you don’t want to help me, then fine, but I thought this was a community that I could ask for help in.

johnwargo, 2025-02-01:
Let me start over. Hi, I'm @johnwargo. I'm new to this project but I'm a long time [Arduino](https://johnwargo.com/categories/arduino/), Raspberry Pi, [ESP32](https://johnwargo.com/categories/esp32/) developer and a contributor to multiple projects on GitHub.

I purchased the Info Orbs kit and I absolutely love it.  I want to make an enclosure for it but I'm not sure yet whether I'm going to 3D print one or build it out of wood, perhaps cut with a LASER cutter. I have no experience with PCB design tools and very little experience with 3D design tools.

I'm looking for the complete dimensions for the board.  I was able to extract just the board layer from the PCB files, so I have the outside dimensions I need. What I'm looking for is the specific location and diameter of the bolt holes on the board as well as the positions and dimensions of the external components (power connector, buttons, female header pins for the displays). With all of that information, I can easily design a 3D printable or LASER cuttable enclosure (and, of course, share it with the community).

Yes, I know that I can measure them on the board, but I'd prefer to not do that if I can.  I also know that some PCB design tools allow you to export/save an image of the board with the dimensions laid out like the image I shared earlier in this Issue. If this is possible, can someone with the experience with PCB design tools is on this discussion either extract those dimensions and share them here so others can leverage them as well or export a file like the one I showed above and add it to the repository so it's part of the project going forward?

If you can't help me with this request, I understand. If you can, I'd be grateful. Failing that, I'll just measure it myself and deal with the potential inaccuracies that come with manual measurement.

lyricnz, 2025-02-19:
Hi @johnwargo . Is there some problem with just installing KiCad and then opening the design files, then using the measurement tool to show you dimensions you're interested in? Eg

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

I am also not a PCB designer - I literally installed the software to answer this question.

lyricnz, 2025-02-19:
@johnwargo Also you can use the Dimension tools to add multiple measurements on your PCB

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

lyricnz, 2025-02-19:
https://docs.kicad.org/6.0/ru/pcbnew/pcbnew_inspecting.html#measurement_tool

https://docs.kicad.org/6.0/ru/pcbnew/pcbnew_editing.html#dimensions

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

johnwargo, 2025-02-19:
@lyricnz no, there isn't a problem with me installing KiCad myself and figuring it out, I already mentioned that in my rewritten response. I don't want to learn KiCad, but I know that I could.

You and @HugoBalder (in a deleted response) are so quick to chastise me about not doing it myself that you're missing the bigger opportunity here. When you look online, you'll find that many Info Orbs owners designed and published 3D plans for enclosures for the device. I imagine that there are many others like me that built or are planning to build enclosures out of wood or perhaps other materials for the device.

Because you seem so opposed to simply adding the dimensions to the open source repository, each and every one of these enthusiasts must perform those steps individually. Either manually measuring the board and hole placement or opening KiCad and generating the dimensions themselves. Think of how helpful it would be for the **Community** if it simply included that file as part of the regular distribution.

Rather than doing all that work to:

1. Download and install KiCad
2. Learn how to document the dimensions of the board
3. Write three chastising responses on my Github issue

You instead simply did some of that work (ignoring the chastising) then submitted the dimensioned image in a pull request on the repo. That would be less work for you and makes it easier for anyone who follows me wanting to ask the same question to get what they need without having to be chastised.

I am so very sorry that I even asked my question. I'm used to working in open source repositories where the community **wants** to help rather than feel superior to new people on the forum.

lyricnz, 2025-02-19:
I don't know who you think "community" is, if it's not just people like you and I. Every single person here (except Brett) are just people who bought the kit, or liked the idea, and got involved. Some of us help, contribute, share. There are no workers to do this work - only us.  Your idea is useful - great - so do it yourself and contribute the result. That's open-source, brother.

johnwargo, 2025-02-19:
My sincerest and humblest apologies for even suggesting a change to the project.

lyricnz, 2025-02-22:
I attempted to add dimensions to the file, but I think I'm hitting some grid/snap issue, so some of the measurements look a bit off.  But it looks like the design isn't "perfect"?  Eg: look at the bottom of the purple boxes: one is above the line, one is on the line, one is below the line:

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

Which means that the corner-to-corner (4.6267) lengths aren't quite the same as the edge-to-edge (4.6250)?

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

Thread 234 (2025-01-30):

Alternative power orientation

johnwargo, 2025-01-30:
I'm planning on building a wooden enclosure for my device and, for a variety of reasons, I don't want the power connector sticking out the back of the top of the enclosure. If the headers weren't installed on the USB connector, I could use an angled headers instead and point the power connector down into the enclosure, hiding it from the top back of the enclosure.

So, that's my feature request.

From an implementation standpoint, can you tell me where you got the power connector board?  I want to see if I can get one without headers to solve my problem.

HugoBalder, 2025-01-31:
I have mine from Amazon -> https://www.amazon.de/dp/B0C6D3MXK9

johnwargo, 2025-01-31:
yeah, that works. Here it is for US: https://www.amazon.com/XUGERIP-Breakout-Type-C-Connector-Converter/dp/B0DFQD7XWH

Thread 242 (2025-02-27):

Make it a little easier to do breakpoint debugging

dreed47, 2025-02-27:
The intent would be to make it easier to do breakpoint real time debugging of the app.  This is very difficult today for the following reasons.

1. Breakpoint debugging on the esp platform requires JTAG ([link to espressif docs](https://docs.espressif.com/projects/esp-idf/en/stable/esp32/api-guides/jtag-debugging/index.html#)).  Many of the recent esp32 dev kits have JTAG builtin but the original esp32 / esp32D that we use does NOT so you have to use a JTAG adapter ([like the ESP-Prog dev board from Espressif](https://www.amazon.com/Espressif-ESP-Prog-Development-Board/dp/B09D3VGR78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)) which is relatively inexpensive.
2.  JTAG requires pins 12, 13, 14, 15 to be free.  Our current PCB uses 3 of these 4 pins so currently its not possible to do breakpoint debugging using this PCB.  You either need to breadboard it or have a custom PCB. (changing our current PCB to not use these pins would break existing boards that have been shipped so it's probably a conversation for a Version 2 board if that ever happens) ([a debug ONLY version of PCB here -USE AT YOUR OWN RISK ](https://github.com/dreed47/info-orb-debug-tools))
3.  To do breakpoint debugging you need to compile with debug flags.  This can cause some issues but most notably the resulting debug binary is too large for the way we have the partitions defined.  That can be handled by using a paritions-debug.csv when compiling for debug.

If we do a little restructuring of the platformio.ini file we can address the debug compile issue while not affecting the non-debug environment.

flattermann, 2025-03-02:
Fixed by #243

Closed 2025-03-02.

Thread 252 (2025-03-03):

Add (optional?) timestamp to serial output

lyricnz, 2025-03-03:
This would help us identify the timing when working on issues that may be related (eg: network or NTP or background updates etc). Relates to #220

lyricnz, 2025-03-03:
Right now, output is a mixture of `Log` output and `Serial.print`.  Making output a bit of a mixed bag:

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

lyricnz, 2025-03-03:
Q: should the logging use the native time on the device (which appears to start at 00:00:00 - see above), or the time we get from NTP (GlobalTime)?

flattermann, 2025-03-04:
Implemented in #261

lyricnz, 2025-03-04:
I'm going to add support for printing the NTP time, not just the hardware/offset time.

Closed 2025-03-04.

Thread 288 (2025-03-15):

Use a single config for weather feed

flattermann, 2025-03-15:
Instead of
```
// WEATHER CONFIGURATION (ONLY SET ONE FEED TO TRUE)
#define WEATHER_VISUALCROSSING_FEED true
#define WEATHER_OPENWEATHERMAP_FEED false
#define WEATHER_TEMPEST_FEED false
```

I think an enum would be better, e.g.

```
enum WeatherFeedType {
  VISUALCROSSING = 0,
  OPENWEATHERMAP,
  TEMPEST
}
```

```
// WEATHER CONFIGURATION
#define WEATHER_FEED VISUALCROSSING
```

This would look cleaner in the config.h.

nconner-06, 2025-03-15:
then change the createWeatherFeed function to a 'switch' statement:
    switch (WEATHER_FEED){
        case (VISUALCROSSING): {
            return new VisualCrossingFeed(WEATHER_VISUALCROSSING_API_KEY, weatherUnits);
        }
        case (OPENWEATHERMAP): {
            return new OpenWeatherMapFeed(WEATHER_OPENWEATHERMAP_API_KEY, weatherUnits);
        }
        case (TEMPEST): {
            return new TempestFeed(WEATHER_TEMPEST_API_KEY, weatherUnits);
        }
    }

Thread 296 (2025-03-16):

incorrect time shown on clock when switching widgets

nconner-06, 2025-03-16:
when you change widgets, the clock widget briefly shows the old time before refreshing

This is caused because WidgetSet::switchWidget, is calling "setup" rather than "update":

void WidgetSet::switchWidget() {
    m_screenManager->clearAllScreens();
    getCurrent()->**setup**();
    uint32_t start = millis();
    getCurrent()->draw(true);
    uint32_t end = millis();
    Serial.printf("Drawing of %s took %d ms\n", getCurrent()->getName().c_str(), (end - start));
}

should be getCurrent()->update();

flattermann, 2025-03-17:
Please do not remove `setup()` here, because this is also used by the widgets to know that they are about to be displayed.
e.g. the ParqetWidget uses it to always start with the first screen.

(And yes, we should implement a better lifecycle management, e.g. like android (onCreate(), onResume(), onPause()...)

But adding `.update()` after `.setup()` here should work.

nconner-06, 2025-03-17:
ok, but for me, setup should only be called ONCE when the orb starts and not every time we cycle to it..

flattermann, 2025-03-17:
Yes, that's definitely more logical.

As soon as we implement some other lifecycle hooks (e.g. onResume()/onPause() if we cycle to/from a widget) we can remove it here.

dreed47, 2025-03-28:
calling getCurrent()->update(); at switchWidget is causing the clockwidget to draw with missing digits.  See issue #310 .  This change got moved into dev with PR #271    I submitted PR #312 to revert this in dev

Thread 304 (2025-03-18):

5Zone widget and Async HTTP requests

dreed47, 2025-03-18:
While testing the 5zone widget, startup seems to take a lot longer due to waiting for initial time zone API requests.   Those API requests also seem to be locking up the UI in some cases.  These requests should be done async using TaskManager so startup is not delayed and UI doeesnt get locked up.  Also should include a default Loading message while the API's are returning.

HugoBalder, 2025-03-19:
Oh boy, the code quality and testing before even thinking to create a Pull Request is getting lower and lower when i once created my PR‘s :( Maybe it will get better in the future.

brett-dot-tech, 2025-03-19:
Thanks for this @dreed47, my bad for not catching this while merging. I'll work to see if I can fix on my end.

@HugoBalder while I appreciate the sentiment of your comment it's not helpful at all to anyone.
This is an open source project with folks of varying skill levels (of which I am on the lower end of) that I am doing my best to accommodate and make sure all willing to contribute are able to do so, and I'm still learning!

Suggestions, feedback, changes and help are VERY welcomed(+encouraged!!) and I do my best to accommodate any and all of them, however empty criticism is not helpful.

dreed47, 2025-03-19:
I didn't realize there was already a loading messages. I just didn't see them.  I get your point about having data preloaded but as a general rule any long running operation like an http request should be done async otherwise it completely blocks the main loop and everything appears locked up until it finishes. That's compounded when we have to do multiple http requests one for each screen

dreed47, 2025-03-19:
If we really wanted to home up the startup until all data is ready we should use a semaphore

flattermann, 2025-03-19:
I would prefer the startup to **not** be blocked, but to load all data in a background thread.

Especially if we add more widgets, the time-to-fully-load-all-widgets will go up, but IMO it's better if the user can at least see the clock while the data is still loading.

nconner-06, 2025-03-19:
I'm re-writing the startup to use the task manager, so as not to block the Orb

Also, building in the new timer function for the draw frequency

nconner-06, 2025-03-20:
PR #305 created to cover these points

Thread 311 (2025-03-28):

Failed to connect to ESP32

jaybak, 2025-03-28:
After following the instructions, I can't seem to get the ESP32 to enter the write mode.  During the power up, the "boot" button is held and upload is started.  But I always get an error.

_
CURRENT: upload_protocol = esptool
Looking for upload port...
Auto-detected: COM5
Uploading .pio\build\esp32doit-devkit-v1\firmware.bin
esptool.py v4.5.1
Serial port COM5
Connecting......................................

A fatal error occurred: Failed to connect to ESP32: Wrong boot mode detected (0x13)! The chip needs to be in download mode.
For troubleshooting steps visit: https ://docs.espressif.com/projects/esptool/en/latest/troubleshooting. html
*** [upload] Error 2
============================ [FAILED] Took 21.84 seconds =====================
_

I can connect to the ESP32 via serial port COM5.  I've added both the universal and the basic windows drivers.  This error happens when the chip is connected to the circuit and when its isolated.  USB C cable is tested and is a good data cable.  VSC on an updated Win 11 PC.

How can I force the "write"  mode and upload the code?

flattermann, 2025-03-31:
Did you keep pressing the boot button from power up until the flashing process begins? (i.e. until Connecting..... )

jaybak, 2025-03-31:
> Did you keep pressing the boot button from power up until the flashing process begins? (i.e. until Connecting..... )

Yes with no luck.  Is it a bad chip or could some odd Win 11 setting blocking me?  The VSC can see the chip on COM5.

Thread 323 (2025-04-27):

Compilation failed

kerat71, 2025-04-27:
Hi everyone,
I got stuck with new version of Info Orbs.
Here how PlatformIO stops:
Processing esp32doit-devkit-v1 (platform: espressif32; board: esp32doit-devkit-v1; framework: arduino)
------------------------------------------------------------------------------------------------------------------------------------------------------
Verbose mode can be enabled via `-v, --verbose` option
CONFIGURATION: https://docs.platformio.org/page/boards/espressif32/esp32doit-devkit-v1.html
PLATFORM: Espressif 32 (54.3.20) > DOIT ESP32 DEVKIT V1
HARDWARE: ESP32 240MHz, 320KB RAM, 4MB Flash
DEBUG: Current (cmsis-dap) External (cmsis-dap, esp-bridge, esp-prog, iot-bus-jtag, jlink, minimodule, olimex-arm-usb-ocd, olimex-arm-usb-ocd-h, olimex-arm-usb-tiny-h, olimex-jtag-tiny, tumpa)
PACKAGES:
 - framework-arduinoespressif32 @ 3.2.0
 - framework-arduinoespressif32-libs @ 5.4.0+sha.2f7dcd862a
 - tool-esptoolpy @ 4.8.9
 - tool-mklittlefs @ 3.2.0
 - tool-riscv32-esp-elf-gdb @ 14.2.0+20240403
 - tool-xtensa-esp-elf-gdb @ 14.2.0+20240403
 - toolchain-xtensa-esp-elf @ 14.2.0+20241119
LDF: Library Dependency Finder -> https://bit.ly/configure-pio-ldf
LDF Modes: Finder ~ chain, Compatibility ~ soft
Found 50 compatible libraries
Scanning dependencies...
Dependency Graph
|-- SPI @ 3.2.0
|-- FS @ 3.2.0
|-- SPIFFS @ 3.2.0
|-- LittleFS @ 3.2.0
|-- SD @ 3.2.0
|-- NTPClient @ 3.2.1
|-- ArduinoJson @ 7.4.1
|-- StreamUtils @ 1.9.0
|-- TFT_eSPI @ 2.5.43
|-- TJpg_Decoder @ 1.1.0
|-- PubSubClient @ 2.8.0
|-- Time @ 1.6.1
|-- WiFiManager @ 2.0.17
|-- HTTPClient @ 3.2.0
|-- WiFi @ 3.2.0
|-- OpenFontRender
Building in release mode
Converting .pio/build/esp32doit-devkit-v1/logo.jpg.txt.o
Converting .pio/build/esp32doit-devkit-v1/moonCloudW.jpg.txt.o
Converting .pio/build/esp32doit-devkit-v1/sunCloudsW.jpg.txt.o
Converting .pio/build/esp32doit-devkit-v1/sunW.jpg.txt.o
Converting .pio/build/esp32doit-devkit-v1/moonW.jpg.txt.o
Converting .pio/build/esp32doit-devkit-v1/snowW.jpg.txt.o
Converting .pio/build/esp32doit-devkit-v1/rainW.jpg.txt.o
Converting .pio/build/esp32doit-devkit-v1/cloudsW.jpg.txt.o
Converting .pio/build/esp32doit-devkit-v1/moonCloudB.jpg.txt.o
Converting .pio/build/esp32doit-devkit-v1/sunCloudsB.jpg.txt.o
Converting .pio/build/esp32doit-devkit-v1/sunB.jpg.txt.o
Converting .pio/build/esp32doit-devkit-v1/moonB.jpg.txt.o
Converting .pio/build/esp32doit-devkit-v1/snowB.jpg.txt.o
Converting .pio/build/esp32doit-devkit-v1/rainB.jpg.txt.o
Converting .pio/build/esp32doit-devkit-v1/cloudsB.jpg.txt.o
Converting .pio/build/esp32doit-devkit-v1/0.jpg.txt.o
Converting .pio/build/esp32doit-devkit-v1/1.jpg.txt.o
Converting .pio/build/esp32doit-devkit-v1/2.jpg.txt.o
Converting .pio/build/esp32doit-devkit-v1/3.jpg.txt.o
Converting .pio/build/esp32doit-devkit-v1/4.jpg.txt.o
Converting .pio/build/esp32doit-devkit-v1/5.jpg.txt.o
Converting .pio/build/esp32doit-devkit-v1/6.jpg.txt.o
Converting .pio/build/esp32doit-devkit-v1/7.jpg.txt.o
Converting .pio/build/esp32doit-devkit-v1/8.jpg.txt.o
Converting .pio/build/esp32doit-devkit-v1/9.jpg.txt.o
Converting .pio/build/esp32doit-devkit-v1/colon_on.jpg.txt.o
Converting .pio/build/esp32doit-devkit-v1/colon_off.jpg.txt.o
Converting .pio/build/esp32doit-devkit-v1/custom_0.jpg.txt.o
Converting .pio/build/esp32doit-devkit-v1/custom_1.jpg.txt.o
Converting .pio/build/esp32doit-devkit-v1/custom_2.jpg.txt.o
Converting .pio/build/esp32doit-devkit-v1/custom_3.jpg.txt.o
Converting .pio/build/esp32doit-devkit-v1/custom_4.jpg.txt.o
Converting .pio/build/esp32doit-devkit-v1/custom_5.jpg.txt.o
Converting .pio/build/esp32doit-devkit-v1/custom_6.jpg.txt.o
Converting .pio/build/esp32doit-devkit-v1/custom_7.jpg.txt.o
Converting .pio/build/esp32doit-devkit-v1/custom_8.jpg.txt.o
Converting .pio/build/esp32doit-devkit-v1/custom_9.jpg.txt.o
Converting .pio/build/esp32doit-devkit-v1/custom_colon_on.jpg.txt.o
Converting .pio/build/esp32doit-devkit-v1/custom_colon_off.jpg.txt.o
Converting .pio/build/esp32doit-devkit-v1/RobotoRegular.ttf.txt.o
Converting .pio/build/esp32doit-devkit-v1/FinalFrontier.ttf.txt.o
Converting .pio/build/esp32doit-devkit-v1/DSEG7ModernBold.ttf.txt.o
Converting .pio/build/esp32doit-devkit-v1/DSEG14ModernBold.ttf.txt.o
Compiling .pio/build/esp32doit-devkit-v1/src/core/button/Button.cpp.o
Compiling .pio/build/esp32doit-devkit-v1/src/core/globaltime/GlobalTime.cpp.o
Compiling .pio/build/esp32doit-devkit-v1/src/core/screenmanager/ScreenManager.cpp.o
Compiling .pio/build/esp32doit-devkit-v1/src/core/utils/Utils.cpp.o
Compiling .pio/build/esp32doit-devkit-v1/src/core/widget/ScreenWidget.cpp.o
Compiling .pio/build/esp32doit-devkit-v1/src/core/widget/Widget.cpp.o
Compiling .pio/build/esp32doit-devkit-v1/src/core/widget/WidgetSet.cpp.o
Compiling .pio/build/esp32doit-devkit-v1/src/main.cpp.o
Compiling .pio/build/esp32doit-devkit-v1/src/widgets/clockwidget/ClockWidget.cpp.o
Compiling .pio/build/esp32doit-devkit-v1/src/widgets/mqttwidget/MQTTWidget.cpp.o
Compiling .pio/build/esp32doit-devkit-v1/src/widgets/parqetwidget/ParqetDataModel.cpp.o
Compiling .pio/build/esp32doit-devkit-v1/src/widgets/parqetwidget/ParqetHoldingDataModel.cpp.o
Compiling .pio/build/esp32doit-devkit-v1/src/widgets/parqetwidget/ParqetWidget.cpp.o
Compiling .pio/build/esp32doit-devkit-v1/src/widgets/stockwidget/StockDataModel.cpp.o
Compiling .pio/build/esp32doit-devkit-v1/src/widgets/stockwidget/StockWidget.cpp.o
Compiling .pio/build/esp32doit-devkit-v1/src/widgets/weatherwidget/WeatherDataModel.cpp.o
Compiling .pio/build/esp32doit-devkit-v1/src/widgets/weatherwidget/WeatherWidget.cpp.o
Compiling .pio/build/esp32doit-devkit-v1/src/widgets/webdatawidget/WebDataElement.cpp.o
Compiling .pio/build/esp32doit-devkit-v1/src/widgets/webdatawidget/WebDataElementArcModel.cpp.o
Compiling .pio/build/esp32doit-devkit-v1/src/widgets/webdatawidget/WebDataElementCharacterModel.cpp.o
Compiling .pio/build/esp32doit-devkit-v1/src/widgets/webdatawidget/WebDataElementCircleModel.cpp.o
Compiling .pio/build/esp32doit-devkit-v1/src/widgets/webdatawidget/WebDataElementImageModel.cpp.o
Compiling .pio/build/esp32doit-devkit-v1/src/widgets/webdatawidget/WebDataElementLineModel.cpp.o
Compiling .pio/build/esp32doit-devkit-v1/src/widgets/webdatawidget/WebDataElementModel.cpp.o
Compiling .pio/build/esp32doit-devkit-v1/src/widgets/webdatawidget/WebDataElementRectangleModel.cpp.o
Compiling .pio/build/esp32doit-devkit-v1/src/widgets/webdatawidget/WebDataElementTextModel.cpp.o
Compiling .pio/build/esp32doit-devkit-v1/src/widgets/webdatawidget/WebDataElementTriangleModel.cpp.o
Compiling .pio/build/esp32doit-devkit-v1/src/widgets/webdatawidget/WebDataModel.cpp.o
Compiling .pio/build/esp32doit-devkit-v1/src/widgets/webdatawidget/WebDataWidget.cpp.o
Compiling .pio/build/esp32doit-devkit-v1/src/widgets/wifiwidget/WifiWidget.cpp.o
Building .pio/build/esp32doit-devkit-v1/bootloader.bin
esptool.py v4.8.9
Creating esp32 image...
Merged 2 ELF sections
Successfully created esp32 image.
Generating partitions .pio/build/esp32doit-devkit-v1/partitions.bin
Compiling .pio/build/esp32doit-devkit-v1/lib4b1/SPI/SPI.cpp.o
Compiling .pio/build/esp32doit-devkit-v1/lib2da/FS/FS.cpp.o
Compiling .pio/build/esp32doit-devkit-v1/lib2da/FS/vfs_api.cpp.o
Compiling .pio/build/esp32doit-devkit-v1/lib3bf/SPIFFS/SPIFFS.cpp.o
Compiling .pio/build/esp32doit-devkit-v1/lib9e7/LittleFS/LittleFS.cpp.o
In file included from .pio/libdeps/esp32doit-devkit-v1/WiFiManager/WiFiManager.h:94,
                 from firmware/src/widgets/wifiwidget/WifiWidget.cpp:4:
/home/milen/.platformio/packages/framework-arduinoespressif32/libraries/WebServer/src/WebServer.h:222:32: error: 'FS' was not declared in this scope; did you mean 'fs::FS'?
  222 |   typedef std::function<String(FS &fs, const String &fName)> ETagFunction;
      |                                ^~
      |                                fs::FS
compilation terminated due to -Wfatal-errors.
Compiling .pio/build/esp32doit-devkit-v1/lib1d1/SD/SD.cpp.o
*** [.pio/build/esp32doit-devkit-v1/src/widgets/wifiwidget/WifiWidget.cpp.o] Error 1
Archiving .pio/build/esp32doit-devkit-v1/lib4b1/libSPI.a
Indexing .pio/build/esp32doit-devkit-v1/lib4b1/libSPI.a
============================================================= [FAILED] Took 8.41 seconds =============================================================

Please, help! What am I missing?

dreed47, 2025-04-28:
is this the main branch or the dev branch?  I would recommend you try the dev branch.

kerat71, 2025-04-28:
Yes, this is the main branch. I will try the dev branch to what will happen. Thanks for the answer.

HugoBalder, 2025-04-29:
I just downloaded the Main Version here - openend the Workspace in Visual Studio Code, waited until the spinning circle in the lower right corner stopped, copied the config.h.template to config.h and let it compile. Everything worked fine without errors.

My version of Visual Studio Code and Platform IO on a Windows 11 machine here:

Version: 1.99.3 (user setup)
Commit: 17baf841131aa23349f217ca7c570c76ee87b957
Date: 2025-04-15T23:18:46.076Z
Electron: 34.3.2
ElectronBuildId: 11161073
Chromium: 132.0.6834.210
Node.js: 20.18.3
V8: 13.2.152.41-electron.0
OS: Windows_NT x64 10.0.26100

Platform IO Version Core 6.1.18 - Home 3.4.4

So the Main branch is ok and can be compiled without errors.
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
kerat71, 2025-05-03:
If I add "#include <WiFiUdp.h" in GlobalTime.h the compilation process ends up exactly like my OP:

`In file included from .pio/libdeps/esp32doit-devkit-v1/WiFiManager/WiFiManager.h:94,
                 from firmware/src/widgets/wifiwidget/WifiWidget.cpp:4:
C:/Users/user/.platformio/packages/framework-arduinoespressif32/libraries/WebServer/src/WebServer.h:222:32: error: 'FS' was not declared in this scope; did you mean 'fs::FS'?
  222 |   typedef std::function<String(FS &fs, const String &fName)> ETagFunction;
      |                                ^~
      |                                fs::FS
compilation terminated due to -Wfatal-errors.`

witch is most likely library issue?

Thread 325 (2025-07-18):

Automatic Dimming

shemers42, 2025-07-18:
Support automatic dimming of the displays in response to changes in room lighting. Room lighting level can be sensed with a simple hardware modification that entails adding a photoresistor and a fixed resistor to the break out area on the info orbs circuit board. Software changes will allow periodic checking of the room lighting and adjusting the displays accordingly.

shemers42, 2025-07-18:
I have the code for this done, but it is currently on gitlab. I'm figuring out the best way to get it to github so I can issue a pull request.

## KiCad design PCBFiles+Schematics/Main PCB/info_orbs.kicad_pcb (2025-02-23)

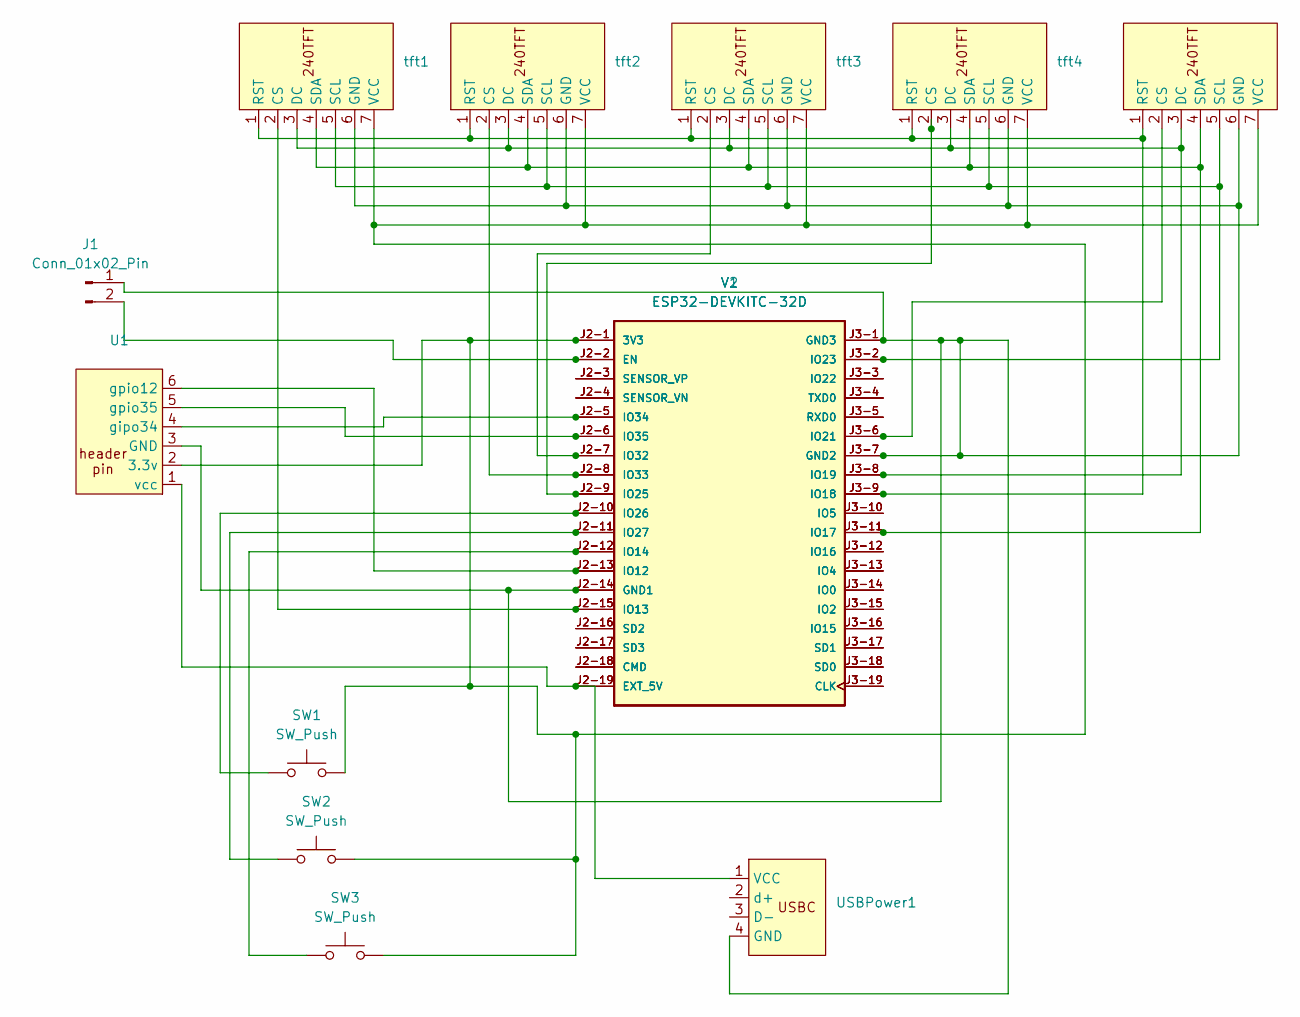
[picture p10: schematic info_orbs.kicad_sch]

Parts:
J1: Conn_01x02_Pin; PinHeader_1x02_P2.54mm_Vertical
SW1, SW2, SW3: SW_Push; SW_PUSH_6mm_H5mm
U1: PinHeader_1x06_P2.54mm_Vertical
USBPower1: PinHeader_1x04_P2.54mm_Vertical
V1: ESP32-DEVKITC-32D; 38 Pin Board; PARTREV V4
V2: ESP32-DEVKITC-32D; 38 Pin Board thin; PARTREV V4
tft1, tft2, tft3, tft4, tft5: PinHeader_1x07_P2.54mm_Vertical

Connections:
unnamed: J1.1, U1.3 (GND), USBPower1.4 (GND), V1.J2-14 (GND1), V1.J3-1 (GND3), V1.J3-7 (GND2), V2.J2-14 (GND1), V2.J3-1 (GND3), V2.J3-7 (GND2), tft1.6 (GND), tft2.6 (GND), tft3.6 (GND), tft4.6 (GND), tft5.6 (GND)
unnamed: J1.2, V1.J2-2 (EN), V2.J2-2 (EN)
unnamed: SW1.2, SW2.2, SW3.2, U1.2 (3.3v), V1.J2-1 (3V3), V2.J2-1 (3V3), tft1.7 (VCC), tft2.7 (VCC), tft3.7 (VCC), tft4.7 (VCC), tft5.7 (VCC)
unnamed: U1.4 (gipo34), V1.J2-5 (IO34), V2.J2-5 (IO34)
unnamed: U1.6 (gpio12), V1.J2-13 (IO12), V2.J2-13 (IO12)
unnamed: U1.5 (gpio35), V1.J2-6 (IO35), V2.J2-6 (IO35)
unnamed: U1.1 (vcc), USBPower1.1 (VCC), V1.J2-19 (EXT_5V), V2.J2-19 (EXT_5V)
unnamed: V1.J3-19 (CLK), V2.J3-19 (CLK)
unnamed: V1.J2-18 (CMD), V2.J2-18 (CMD)
unnamed: V1.J3-14 (IO0), V2.J3-14 (IO0)
unnamed: V1.J3-15 (IO2), V2.J3-15 (IO2)
unnamed: V1.J3-13 (IO4), V2.J3-13 (IO4)
unnamed: V1.J3-10 (IO5), V2.J3-10 (IO5)
unnamed: V1.J2-15 (IO13), V2.J2-15 (IO13), tft1.2 (CS)
unnamed: SW3.1, V1.J2-12 (IO14), V2.J2-12 (IO14)
unnamed: V1.J3-16 (IO15), V2.J3-16 (IO15)
unnamed: V1.J3-12 (IO16), V2.J3-12 (IO16)
unnamed: V1.J3-11 (IO17), V2.J3-11 (IO17), tft1.4 (SDA), tft2.4 (SDA), tft3.4 (SDA), tft4.4 (SDA), tft5.4 (SDA)
unnamed: V1.J3-9 (IO18), V2.J3-9 (IO18), tft1.1 (RST), tft2.1 (RST), tft3.1 (RST), tft4.1 (RST), tft5.1 (RST)
unnamed: V1.J3-8 (IO19), V2.J3-8 (IO19), tft1.3 (DC), tft2.3 (DC), tft3.3 (DC), tft4.3 (DC), tft5.3 (DC)
unnamed: V1.J3-6 (IO21), V2.J3-6 (IO21), tft5.2 (CS)
unnamed: V1.J3-3 (IO22), V2.J3-3 (IO22)
unnamed: V1.J3-2 (IO23), V2.J3-2 (IO23), tft1.5 (SCL), tft2.5 (SCL), tft3.5 (SCL), tft4.5 (SCL), tft5.5 (SCL)
unnamed: V1.J2-9 (IO25), V2.J2-9 (IO25), tft4.2 (CS)
unnamed: SW1.1, V1.J2-10 (IO26), V2.J2-10 (IO26)
unnamed: SW2.1, V1.J2-11 (IO27), V2.J2-11 (IO27)
unnamed: V1.J2-7 (IO32), V2.J2-7 (IO32), tft3.2 (CS)
unnamed: V1.J2-8 (IO33), V2.J2-8 (IO33), tft2.2 (CS)
unnamed: V1.J3-5 (RXD0), V2.J3-5 (RXD0)
unnamed: V1.J3-18 (SD0), V2.J3-18 (SD0)
unnamed: V1.J3-17 (SD1), V2.J3-17 (SD1)
unnamed: V1.J2-16 (SD2), V2.J2-16 (SD2)
unnamed: V1.J2-17 (SD3), V2.J2-17 (SD3)
unnamed: V1.J2-4 (SENSOR_VN), V2.J2-4 (SENSOR_VN)
unnamed: V1.J2-3 (SENSOR_VP), V2.J2-3 (SENSOR_VP)
unnamed: V1.J3-4 (TXD0), V2.J3-4 (TXD0)

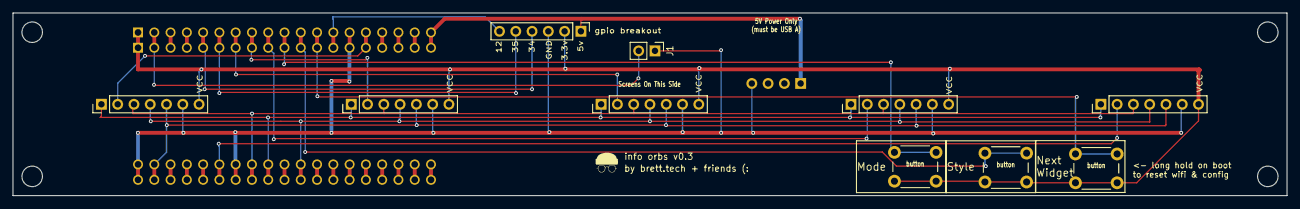
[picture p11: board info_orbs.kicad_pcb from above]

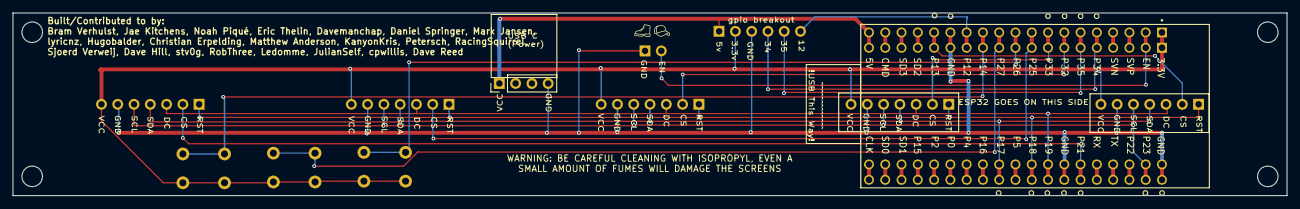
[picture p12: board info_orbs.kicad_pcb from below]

Board: 2 copper layers, 198.8 x 28.5 mm, 14 parts (3 on the bottom side), 36 nets.

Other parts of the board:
G*: LOGO; beaniegraphioc

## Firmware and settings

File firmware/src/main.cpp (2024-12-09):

#include "Button.h"
#include "GlobalTime.h"
#include "ScreenManager.h"
#include "Utils.h"
#include "WidgetSet.h"
#include "clockwidget/ClockWidget.h"
#include "config_helper.h"
#include "icons.h"
#include "weatherwidget/WeatherWidget.h"
#include "webdatawidget/WebDataWidget.h"
#include "wifiwidget/WifiWidget.h"
#include <Arduino.h>

#ifdef STOCK_TICKER_LIST
    #include "stockwidget/StockWidget.h"
#endif
#ifdef PARQET_PORTFOLIO_ID
    #include "parqetwidget/ParqetWidget.h"
#endif
#ifdef MQTT_WIDGET_HOST
    #include "mqttwidget/MQTTWidget.h"
#endif

TFT_eSPI tft = TFT_eSPI();

#ifdef WIDGET_CYCLE_DELAY
unsigned long m_widgetCycleDelay = WIDGET_CYCLE_DELAY * 1000; // Automatically cycle widgets every X seconds, set to 0 to disable
#else
unsigned long m_widgetCycleDelay = 0;
#endif
unsigned long m_widgetCycleDelayPrev = 0;

Button buttonLeft(BUTTON_LEFT);
Button buttonOK(BUTTON_OK);
Button buttonRight(BUTTON_RIGHT);

GlobalTime *globalTime; // Initialize the global time

String connectingString{""};

WifiWidget *wifiWidget{nullptr};

int connectionTimer{0};
const int connectionTimeout{10000};
bool isConnected{true};

ScreenManager *sm;
WidgetSet *widgetSet;

// This function should probably be moved somewhere else
bool tft_output(int16_t x, int16_t y, uint16_t w, uint16_t h, uint16_t *bitmap) {
    if (y >= tft.height())
        return 0;
    // Dim bitmap
    for (int i = 0; i < w * h; i++) {
        bitmap[i] = Utils::rgb565dim(bitmap[i], sm->getBrightness(), true);
    }
    tft.pushImage(x, y, w, h, bitmap);
    return 1;
}

/**
 * The ISR handlers must be static
 */
void isrButtonChangeLeft() { buttonLeft.isrButtonChange(); }
void isrButtonChangeMiddle() { buttonOK.isrButtonChange(); }
void isrButtonChangeRight() { buttonRight.isrButtonChange(); }

void setupButtons() {
    buttonLeft.begin();
    buttonOK.begin();
    buttonRight.begin();

    attachInterrupt(digitalPinToInterrupt(BUTTON_LEFT), isrButtonChangeLeft, CHANGE);
    attachInterrupt(digitalPinToInterrupt(BUTTON_OK), isrButtonChangeMiddle, CHANGE);
    attachInterrupt(digitalPinToInterrupt(BUTTON_RIGHT), isrButtonChangeRight, CHANGE);
}

void setup() {
    Serial.begin(115200);
    Serial.println();
    Serial.println("Starting up...");

    TJpgDec.setSwapBytes(true); // JPEG rendering setup
    TJpgDec.setCallback(tft_output);
    setupButtons();

    sm = new ScreenManager(tft);
    sm->fillAllScreens(TFT_BLACK);
    sm->setFontColor(TFT_WHITE);

    sm->selectScreen(0);
    sm->drawCentreString("Welcome", ScreenCenterX, ScreenCenterY, 29);

    sm->selectScreen(1);
    sm->drawCentreString("Info Orbs", ScreenCenterX, ScreenCenterY - 50, 22);
    sm->drawCentreString("by", ScreenCenterX, ScreenCenterY - 5, 22);
    sm->drawCentreString("brett.tech", ScreenCenterX, ScreenCenterY + 30, 22);
    sm->setFontColor(TFT_RED);
    sm->drawCentreString("version: 1.1.0", ScreenCenterX, ScreenCenterY + 65, 14);

    sm->selectScreen(2);

    TJpgDec.setJpgScale(1);
    TJpgDec.drawJpg(0, 0, logo_start, logo_end - logo_start);

    widgetSet = new WidgetSet(sm);

#ifdef GC9A01_DRIVER
    Serial.println("GC9A01 Driver");
#endif
#if HARDWARE == WOKWI
    Serial.println("Wokwi Build");
#endif

    pinMode(BUSY_PIN, OUTPUT);
    Serial.println("Connecting to WiFi");

    wifiWidget = new WifiWidget(*sm);
    wifiWidget->setup();

    globalTime = GlobalTime::getInstance();

    widgetSet->add(new ClockWidget(*sm));
#ifdef PARQET_PORTFOLIO_ID
    widgetSet->add(new ParqetWidget(*sm));
#endif
#ifdef STOCK_TICKER_LIST
    widgetSet->add(new StockWidget(*sm));
#endif
    widgetSet->add(new WeatherWidget(*sm));
#ifdef WEB_DATA_WIDGET_URL
    widgetSet->add(new WebDataWidget(*sm, WEB_DATA_WIDGET_URL));
#endif
#ifdef WEB_DATA_STOCK_WIDGET_URL
    widgetSet->add(new WebDataWidget(*sm, WEB_DATA_STOCK_WIDGET_URL));
#endif
#ifdef MQTT_WIDGET_HOST
    widgetSet->add(new MQTTWidget(*sm, MQTT_WIDGET_HOST, MQTT_WIDGET_PORT));
#endif

    m_widgetCycleDelayPrev = millis();
}

void checkCycleWidgets() {
    if (m_widgetCycleDelay > 0 && (m_widgetCycleDelayPrev == 0 || (millis() - m_widgetCycleDelayPrev) >= m_widgetCycleDelay)) {
        widgetSet->next();
        m_widgetCycleDelayPrev = millis();
    }
}

void checkButtons() {
    // Reset cycle timer whenever a button is pressed
    if (buttonLeft.pressedShort()) {
        // Left short press cycles widgets backward
        Serial.println("Left button short pressed -> switch to prev Widget");
        m_widgetCycleDelayPrev = millis();
        widgetSet->prev();
    } else if (buttonRight.pressedShort()) {
        // Right short press cycles widgets forward
        Serial.println("Right button short pressed -> switch to next Widget");
        m_widgetCycleDelayPrev = millis();
        widgetSet->next();
    } else {
        ButtonState leftState = buttonLeft.getState();
        ButtonState middleState = buttonOK.getState();
        ButtonState rightState = buttonRight.getState();

        // Everying else that is not BTN_NOTHING will be forwarded to the current widget
        if (leftState != BTN_NOTHING) {
            Serial.printf("Left button pressed, state=%d\n", leftState);
            m_widgetCycleDelayPrev = millis();
            widgetSet->buttonPressed(BUTTON_LEFT, leftState);
        } else if (middleState != BTN_NOTHING) {
            Serial.printf("Middle button pressed, state=%d\n", middleState);
            m_widgetCycleDelayPrev = millis();
            widgetSet->buttonPressed(BUTTON_OK, middleState);
        } else if (rightState != BTN_NOTHING) {
            Serial.printf("Right button pressed, state=%d\n", rightState);
            m_widgetCycleDelayPrev = millis();
            widgetSet->buttonPressed(BUTTON_RIGHT, rightState);
        }
    }
}

void loop() {
    if (wifiWidget->isConnected() == false) {
        wifiWidget->update();
        wifiWidget->draw();
        widgetSet->setClearScreensOnDrawCurrent(); // Clear screen after wifiWidget
        delay(100);
    } else {
        if (!widgetSet->initialUpdateDone()) {
            widgetSet->initializeAllWidgetsData();
        }
        globalTime->updateTime();

        checkButtons();

        widgetSet->updateCurrent();
        widgetSet->updateBrightnessByTime(globalTime->getHour24());
        widgetSet->drawCurrent();

        checkCycleWidgets();
    }
}

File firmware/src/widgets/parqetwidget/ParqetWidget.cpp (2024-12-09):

#include "ParqetWidget.h"

#include "config_helper.h"
#include <ArduinoJson.h>
#include <HTTPClient.h>
#include <StreamUtils.h>

#include <iomanip>

ParqetWidget::ParqetWidget(ScreenManager &manager) : Widget(manager) {
    Serial.println("Constructing ParqetWidget");
    ParqetDataModel parqet = ParqetDataModel();
#ifdef PARQET_PORTFOLIO_ID
    parqet.setPortfolioId(PARQET_PORTFOLIO_ID);
#endif
    m_portfolio = parqet;
}

void ParqetWidget::setup() {
    m_time = GlobalTime::getInstance();
    m_holdingsDisplayFrom = 0;
}

void ParqetWidget::draw(bool force) {
    m_manager.setFont(DEFAULT_FONT);
    // Check if we need more than one page
    bool isMultiPage = m_portfolio.getHoldingsCount() > (m_showClock ? 4 : 5);
    // Do we need to update the screens because cycle time is expired
    bool updateByCycle = isMultiPage && (millis() - m_cycleDelayPrev) >= m_cycleDelay;
    // Do we need to update the clock screen?
    bool updateByClock = m_showClock && (millis() - m_clockDelayPrev) >= m_clockDelay;
    // Do we need to update the stock screens?
    bool updateStocks = force || m_changed || updateByCycle;
    if (updateStocks || updateByClock) {
        int8_t stockDisplays = 5;
        int8_t startDisplay = 0;
        if (m_showClock) {
            // Update the clock in every update
            stockDisplays--;
            startDisplay++;
            int8_t curPage = m_holdingsDisplayFrom / stockDisplays + 1;
            int8_t totalPages = (m_portfolio.getHoldingsCount() - 1) / stockDisplays + 1;
            String extra = String(curPage) + "/" + String(totalPages);
            displayClock(0, TFT_BLACK, TFT_WHITE, extra, TFT_DARKGREY);
            m_clockDelayPrev = millis();
        }
        if (updateStocks) {
            // Update the stocks only if necessary
            for (int8_t i = 0; i < stockDisplays; i++) {
                int8_t displayIdx = startDisplay + i;
                int8_t holdingIdx = m_holdingsDisplayFrom + i;
                if (holdingIdx < m_portfolio.getHoldingsCount()) {
                    ParqetHoldingDataModel holding = m_portfolio.getHolding(holdingIdx);
                    displayStock(displayIdx, holding, TFT_BLACK, TFT_WHITE);
                } else {
                    clearScreen(displayIdx, TFT_BLACK);
                }
            }
            // In the next cycle, show the next set of stocks
            m_holdingsDisplayFrom += stockDisplays;
            if (m_holdingsDisplayFrom >= m_portfolio.getHoldingsCount()) {
                m_holdingsDisplayFrom = 0;
            }
            m_changed = false;
            m_cycleDelayPrev = millis();
        }
    }
    m_everDrawn = true;
}

void ParqetWidget::update(bool force) {
    if (force || m_stockDelayPrev == 0 || (millis() - m_stockDelayPrev) >= m_stockDelay) {
        setBusy(true);
        Serial.println("Update ParqetPortfolio");
        if (m_everDrawn && m_showClock) {
            displayClock(0, TFT_BLACK, TFT_WHITE, "Updating", TFT_RED);
        }
        updatePortfolio();
        updatePortfolioChart();
        m_holdingsDisplayFrom = 0;
        m_changed = true;
        setBusy(false);
        m_stockDelayPrev = millis();
    }
}

void ParqetWidget::buttonPressed(uint8_t buttonId, ButtonState state) {
    if (buttonId == BUTTON_OK && state == BTN_SHORT) {
        // Force drawing to show the next set of stocks
        draw(true);
    } else if (buttonId == BUTTON_OK && state == BTN_MEDIUM) {
        // Change timeframe and force update
        m_curMode++;
        if (m_curMode >= PARQET_MODE_COUNT) {
            m_curMode = 0;
        }
        update(true);
    } else if (buttonId == BUTTON_OK && state == BTN_LONG) {
        // Reset view to default timeframe and reload
        m_curMode = 0;
        update(true);
    }
}

String ParqetWidget::getTimeframe() {
    return m_modes[m_curMode];
}

ParqetDataModel ParqetWidget::getPortfolio() {
    return m_portfolio;
}

void ParqetWidget::updatePortfolio() {
    String portfolioId = m_portfolio.getPortfolioId();
    Serial.printf("Parqet: Update Portfolio %s\n", portfolioId.c_str());
    String httpRequestAddress = "https://api.parqet.com/v1/portfolios/assemble";
    String postPayload = "{ \"portfolioIds\": [\"" + portfolioId + "\"], \"holdingIds\": [], \"assetTypes\": [], \"timeframe\": \"" + getTimeframe() + "\"}";
    Serial.printf("POST Payload: %s\n", postPayload.c_str());
    HTTPClient http;
    const char *keys[] = {"Transfer-Encoding"};
    http.collectHeaders(keys, 1);
    http.begin(httpRequestAddress);
    http.addHeader("Content-Type", "application/json");

    int httpCode = http.POST(postPayload);
    Serial.printf("HTTP %d, Size %d\n", httpCode, http.getSize());

    // Check for the returning code
    if (httpCode == 200) {
        Stream &rawStream = http.getStream();
        ChunkDecodingStream decodedStream(http.getStream());

        // Choose the right stream depending on the Transfer-Encoding header
        // Parqet might send chunked responses
        Stream &response =
            http.header("Transfer-Encoding") == "chunked" ? decodedStream : rawStream;

        // Parse response
        JsonDocument doc;
        JsonDocument filter;
        // Filter the response to save memory
        filter["holdings"] = true;
        filter["performance"] = true;

        DeserializationError error = deserializeJson(doc, response, DeserializationOption::Filter(filter));
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

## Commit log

2024-04-25 Readme Edits, New Wiring Diagram
2024-05-02 bugfix first init time and optimization
    don't put in m_updateTime millis in the init routine, so the time get's updated when it first goes through the loop
2024-05-05 got the menu working with a second widget
    added force draw and update so we can force the widget to update and draw when we switch menu
2024-05-07 Update gitignore, IRL hardware fix
    [main.cpp]
2024-05-08 wiring diagram update
2024-05-08 Add basic sim (not working) and all options in user.h file
    [main.cpp]
2024-05-08 Add wifi boot screen, fix background of clock
    [main.cpp]
2024-05-11 global user.h for all pin defs
2024-05-14 update widget from buttons using WidgetSet
2024-05-15 clean up whitespace fix weather refresh
    [main.cpp]
2024-05-16 update and draw switch
2024-05-22 update configs to match PCB 0.1
2024-05-22 remove fingerprint as it is no longer used or needed
2024-05-30 add pinMode for busy led
2024-05-31 fix buttons on dev pcb 0.1 to not autopress on startup
2024-06-09 fix strange arduino string issue
2024-08-30 Small error fix, deleted some unneeded files
    [info-orbs.kicad_pcb, info-orbs.kicad_sch]
2024-08-30 Added PCB Files (:
    [StandOrbs.kicad_pcb, StandOrbs.kicad_sch, info_orbs.kicad_pcb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]
2024-08-30 Changed board from pico to correct esp32 dev kit in PIO
    Not sure if this matters, but just encase
2024-09-06 Add config option to invert the Orbs. Inverts the screens and re-orders screens and buttons.
2024-10-22 Check for existence of config.h before trying to include it.
    When the file is not included, compilation is terminated and an appropriate error is printed.
    [main.cpp]
2024-10-28 Changed from Widget.changeMode() to Widget.buttonPressed(uint8_t buttonId)
2024-10-28 Reset cycle timer whenever a button is pressed
    [main.cpp]
2024-10-29 Fix switch indent
2024-10-30 Changed signature to Widget.buttonPressed(uint8_t buttonId, ButtonState state)
2024-11-02 Change to new buttonPressed() function
2024-11-02 Updated for new Button logic
2024-11-02 Use short button to cycle, medium button to switch timeframes and long button to switch back to default timeframe
2024-11-02 Fixed wrong buttons in widgets (sorry!)
2024-11-03 Use a single #define (e.g. LOCALE de)
2024-11-03 Variables that are related to millis() should be unsigned long
2024-11-04 Switched to interrupts
2024-11-11 Added partition table
    [partitions.csv]
2024-11-15 Remove unwanted portal buttons
    Removed the unwanted Info, Exit, Update buttons from the WiFi config portal. Also fixed the "Connecting Unknown" bug.
2024-11-16 Unique portal SSID
    Added the last 2 digits of the MAC address to the config portal SSID so each Info-Orbs SSID is unique (in case of multiple naeaby Orbs).
2024-11-20 Log drawing time in switchWidget()
2024-11-20 Switched ParqetWidget to TTF
2024-11-20 Switched to RobotoRegular.ttf as binary file instead of .h, also added FinalFrontier.ttf for later use...
2024-11-20 Switched stockWidget to TTF
2024-11-20 Switched ClockWidget to DSEG
2024-11-20 Switch font back after drawing
2024-11-21 Switched drawString() methods to String
2024-11-24 Dimming is now possible (fixed value for now)
    [main.cpp]
2024-11-25 Added Nixie to ClockWidget (switch using middle button)
2024-11-26 Bugfix for weather refresh not using timer
    Everytime you switch to the weather widget, the data get's reloaded, regardsless of the set refresh time. This changes fixes this.
2024-11-28 [MegaLinter] Apply linters fixes
    [Button.h, GlobalTime.cpp]
2024-11-29 Fixed deprecation warning #133 (as recommended by ArduinoJson7)
    [MQTTWidget.cpp]
2024-11-29 Revert "[MegaLinter] Apply linters fixes"
    This reverts commit 383a57eecaa54a9091c227ca553f56925987dbd5.
    [Button.h, GlobalTime.cpp]
2024-12-02 Switch Highs/Lows only redraw 5th screen
    Currently when switching between Highs/Lows for the 3 days Forecast, all 5 screens are refreshed. With the TTF Font it is slow and not needed. Only the 5th screen needs to be refreshed.
2025-02-23 Updated New PCB Files
    [StandOrbs.kicad_pcb, info_orbs.kicad_pcb, info_orbs.kicad_sch]
2025-02-25 Added PCB dimensions
